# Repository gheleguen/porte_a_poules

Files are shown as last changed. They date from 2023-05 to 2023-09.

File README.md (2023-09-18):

# Porte à poules

Une porte à poules est destiné à automatiser l'ouverture et la fermeture d'un poulailler. Il est équipé d'un capteur de lumière et d'une horloge en temps réel. Le déclenchement de la porte se fait donc à partir d'une certaine heure (défini par l'utilisateur au moyen de potentiomètres) et quand la lumière passe en dessous d'un certain seuil. 

Le système est réalisé sur une base arduino avec un moto-réducteur à courant continu. L'alimentation est opéré par une batterie au plomb chargé par un petit panneau solaire.

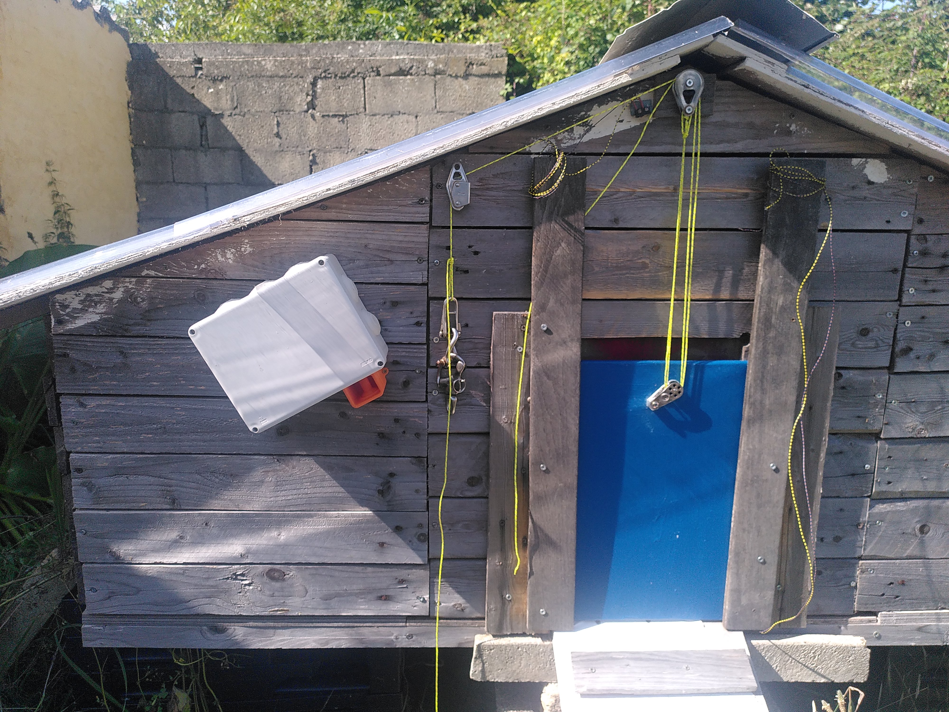
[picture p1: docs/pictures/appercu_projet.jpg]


## Usage de la présente documentation

Toutes la documentation est basé sur une archive git et hébergé sur [github](https://github.com/). 

Afin de fabriquer la porte à poule et de disposer de tous les documents et fichiers nécessaires, je vous recommande de copier l'archive sur votre ordinateur : 
 - En vous rendant directement sur le projet github : https://github.com/gheleguen/porte_a_poules.
 - Ou en exécutant sur un terminal la ligne de commande suivante : ```git clone https://github.com/gheleguen/porte_a_poules```

## 1/ Toutes les clés pour se lancer

### 1.1 Télécharger l'archive

Avant toute chose, [télécharger l'archive du projet](https://github.com/gheleguen/porte_a_poules/archive/refs/heads/main.zip). C'est dans ce dossier que se trouve tous les fichiers de documantations mais aussi les fichiers de découpes ou les modèles d'impression 3D. 

**Ou passer par Git Hub**

Se rendre dans le [git hub](https://github.com/gheleguen/porte_a_poules) et télécharger l'archive complète du projet. 

**Ou en lignes de commandes**

 - Ouvrir un terminal linux,
 - Si ce n'est pas déjà fait installer ```git``` : <pre>sudo apt install git</pre>
 - Se placer dans le dossier de votre ordinateur où vous souhaitez installer enregistrer l'archive.
 - Cloner l'archive : <pre>git clone https://github.com/gheleguen/porte_a_poules</pre> 

### 1.2 L'arborescence de l'archive

 - **docs :** Est le dossier qui contient les documents et images qui constituent la documentation.  Ce sont des fichiers marckdown (.md) que l'on peut ouvrir avec un éditeur de texte.

 - **Hardware :** Le dossier qui contient les fichiers d'impressions 3D, de découpe laser...  

 - **Software :** Le dossier qui contient le code à flasher sur l'arduino.

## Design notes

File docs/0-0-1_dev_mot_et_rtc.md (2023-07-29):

# 0.0.1 -- Un moteur piloté à l'heure

## 1/ Introduction
La première étape du développement de cet outil est de chercher à piloter un moteur à courant continu de 1,5 à 3V au moyen d'une arduino UNO et d'une RTC pour donner l'heure. 
 - Dans cette configuration 2 boutons poussoirs symbolisent, les deux fins de courses. Le moteur devra s'arrêté lorsque le bouton sera enclenché de fin de course correspondant sera enclenché.
 - Une RTC permettra de fournir l'heure en temps réel. Cette donnée permet à la porte de s'ouvrir et de se fermer. 

</br></br>
## 2/ Matériel et fournitures nécessaire
### 2.1 Fournitures
|Dénomination|Visuel|Où se fournir ?|Qt|
|---|---|-----|--|
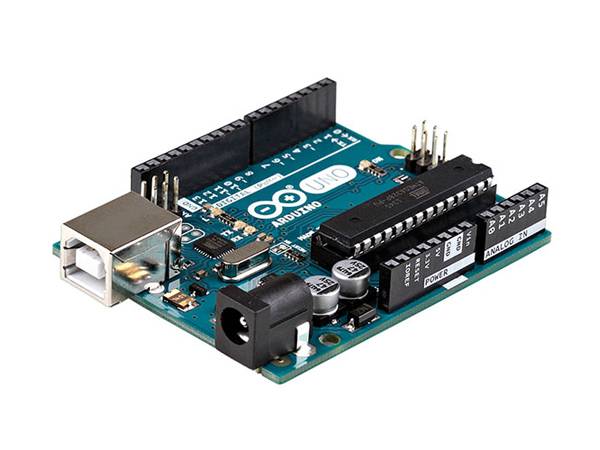
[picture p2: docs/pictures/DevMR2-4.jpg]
|Arduino UNO||Conrad / RS components|1|
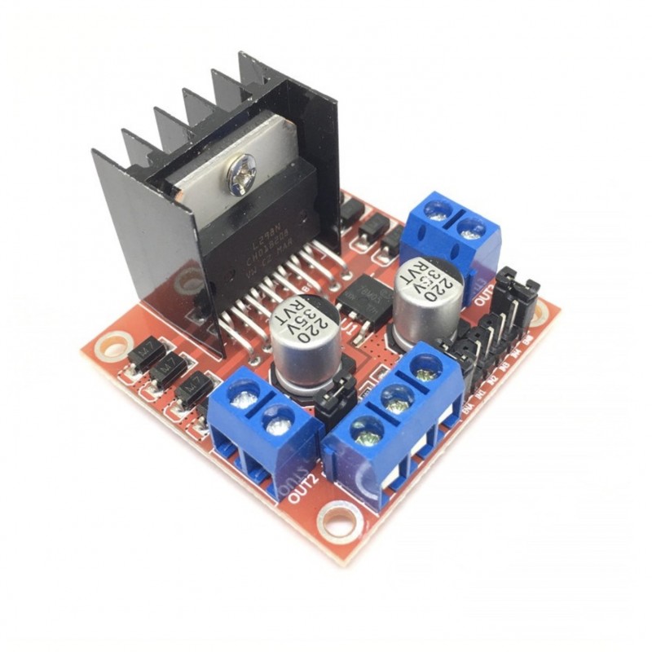
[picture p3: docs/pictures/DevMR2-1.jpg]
DevMR2-1
|Contrôleur moteur - Module L298N||Conrad / RS components|1|
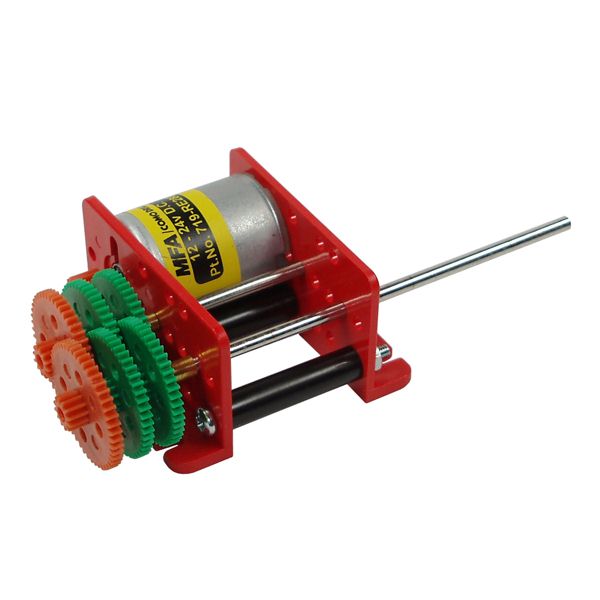
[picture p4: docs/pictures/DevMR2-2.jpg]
DevMR2-2
|Moteur DC (1,5-3v et son reducteur)||RS components|1|
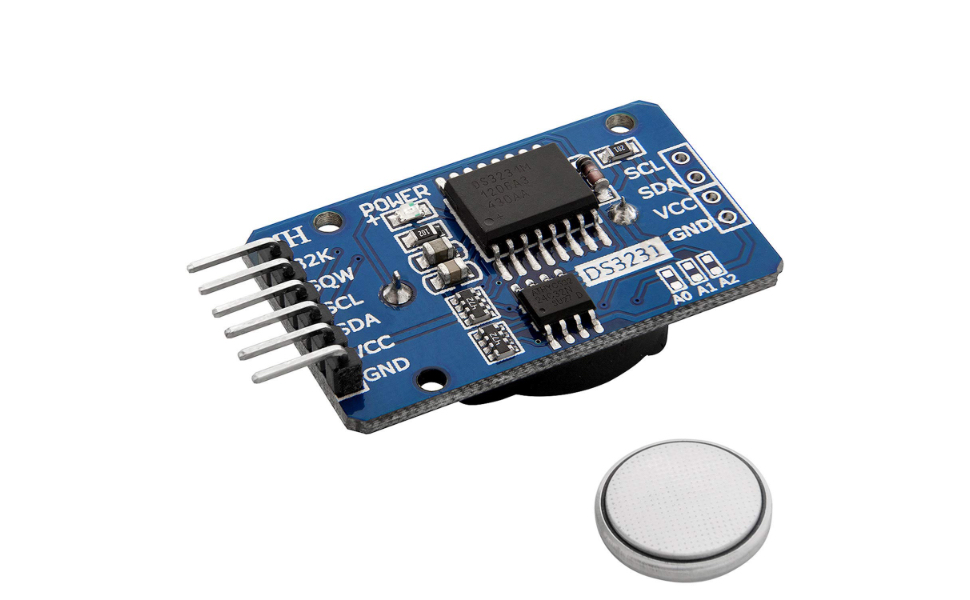
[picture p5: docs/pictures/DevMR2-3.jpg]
|Module horloge RTC DS3231||Conrad / RS components|1|
|Résistances 1Kohm ou autre valeur|||4|
|Boutons poussoirs|||2|
|Batterie 9V ou Bloc piles 9v et pile||Conrad / RS components|1|
|Breadbord|||1|
|Fils de breadbord mâle-mâle et femelle-mâle||||

### 2.2 Matériel
 - Ordinateur
 - [Logiciel Arduino IDE](https://www.arduino.cc/en/software)
 - Câble USB type B vers USB. 

</br></br> 
## 3/ Réalisation
### 3.1 Hardware
Réaliser le circuit représenté ci dessous. [Le fichier fritzing est accessible ici](../hardware)
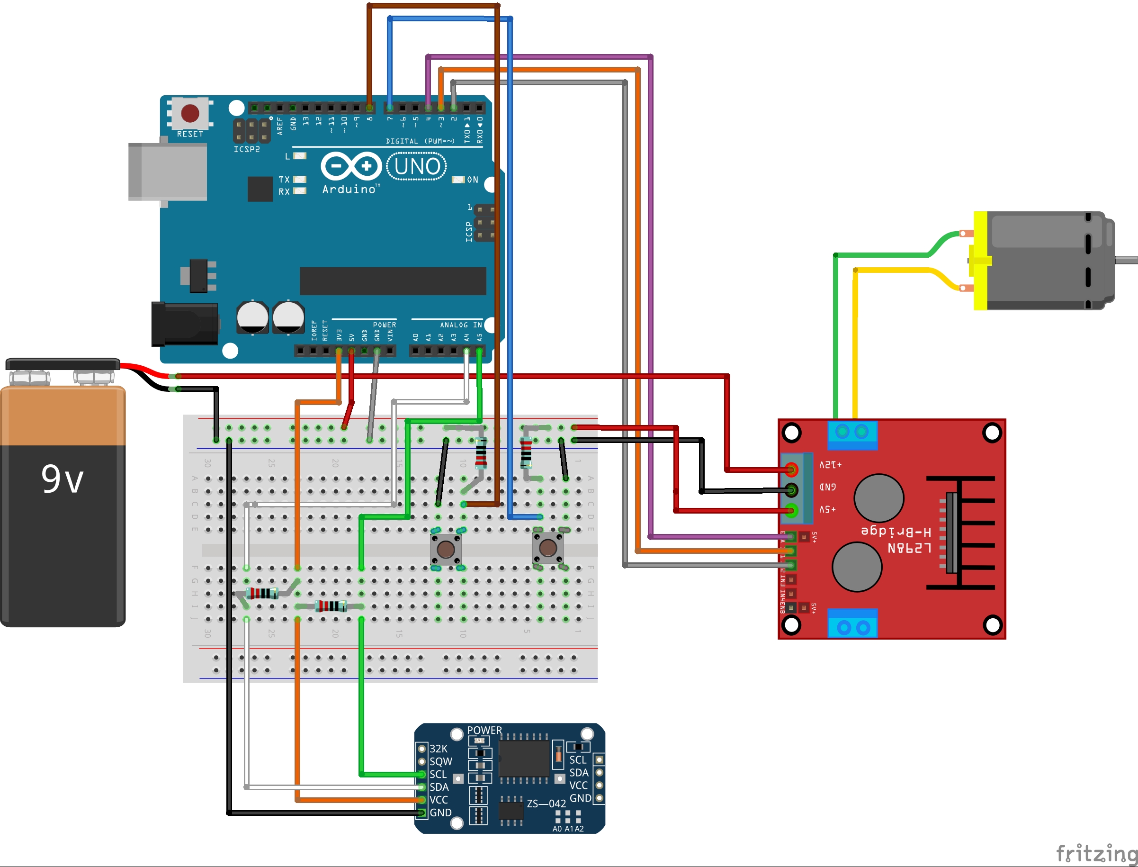
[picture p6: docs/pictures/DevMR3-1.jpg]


### 3.2 Software
Le code suivant se trouvau aussi au format ".ino" dans l'archive dans le dossier "software" sous le nom de "dev_mot_et_rtc.ino".

Flasher au moyen d'Arduino IDE le code suivant :

```cpp
#include <Wire.h>  
#include "DS3231.h"

RTClib RTC;
DS3231 Clock;

//Paramètres de déclenchements de la porte
int Houv = 8; // Heure d'ouverture
int Mouv = 0; // Minute d'ouverture
int Hferm = 17; //Heure de fermeture
int Mferm = 0; // Minute de fermeture

// Branchements
int enA = 4; 
int in1 = 3;
int in2 = 2;
int pin_buttonA = 7; // port numérique lié au bouton poussoir 1
int pin_buttonB = 8; // port numérique lié au bouton poussoir 2

//Introduction de variables
int Year;
int Month;
int Date;
int Hour;
int Minute;
int Second;
int interval = 1;
int Minute_last;
int Date_last;
int i = 0;

void setup()
{
  //Initialise le moniteur série
  Serial.begin(9600);
  Wire.begin(); //for DS3231 for RTC
  
  // Defini tous les ports du contr^leur moteur comme des sorties
  pinMode(enA, OUTPUT);
  pinMode(in1, OUTPUT);
  pinMode(in2, OUTPUT);
  analogWrite(enA, 255); 
  DateTime now = RTC.now();
  Minute = now.minute();
}
 
void loop()
{  
  delay(1000);
  Serial.println();
  Serial.print(Year);
  Serial.print("/");
  Serial.print(Month);
  Serial.print("/");
  Serial.print(Date);
  Serial.print(" ");
  Serial.print(Hour);
  Serial.print(":");
  Serial.print(Minute);
  Serial.print(":");
  Serial.print(Second);
  if (Hour >= Houv && Hour < Hferm && i == 0) { // Si l'heure est supérieur à l'heure minimale d'ouverture et que la porte est fermé
      ouverture(); // Ouverture de la porte
   }
  if (Hour >= Hferm && Hour > Houv && i == 1) { // Si l'heure est supérieur à l'heure minimale de fermeture et que la porte est fermé
      fermeture(); // Ouverture de la porte
   }
  DateTime now = RTC.now();
  Year = now.year();
  Month = now.month();
  Date = now.day();
  Hour = now.hour();
  Minute = now.minute();
  Second = now.second();
}

void ouverture(){
  Serial.println();
  Serial.print("Ouverture de la porte...");
  while (digitalRead(pin_buttonA) == HIGH){ // Tant que le bouton est en position High, le moteur tourne
      //le moteur tourne
      digitalWrite(in1, HIGH);
      digitalWrite(in2, LOW);
  }
  Serial.println();
  Serial.print("Porte ouverte ;-)");
  digitalWrite(in1, LOW);
  digitalWrite(in2, LOW);
  i = 1; // I defini l'etat d'ouverture de la porte, ici i prend la valeur 1 ce qui signifie que la porte est ouverte
  delay(1000);
}

void fermeture(){
  Serial.println();
  Serial.print("Fermeture de la porte...");
  while (digitalRead(pin_buttonB) == HIGH){ // Tant que le bouton est en position High, le moteur tourne
      //le moteur tourne
      digitalWrite(in1, LOW);
      digitalWrite(in2, HIGH);
  }
  Serial.println();
  Serial.print("Porte ferme ;-)");
  digitalWrite(in1, LOW);
  digitalWrite(in2, LOW);
  i = 0;
  delay(1000);
}
```

</br></br>
## 4/ Références et développement. 
J'ai commencé par tester des codes proposé sur le web. Mais tous me rendent des erreurs lié à des librairies.
 - [Ce Tutoriel est réalisé à partir d'un L298N](https://www.instructables.com/Chicken-Coop-Door-Arduino-Based/). Son code ne fonctionne pas du fait d'erreur sur les librairies.
 - [Ce dépot Git Hub peut être intéréssant aussi](https://github.com/chrisuthe/CoopDoor/tree/master/ChickenDoorController) mais comme le précédent il ne fonctionne pas. 

J'ai donc décidé de coder le système moi même :
 - Je suis partis du Tutoriel ci attaché pour faire tourner le moteur[Code et branchements pour faire tourner un moteur avec L298N](https://www.robotique.tech/tutoriel/commander-un-moteur-par-arduino-et-le-module-l298n/). Je suis ainsi parti de ce petit code qui permet de faire tourner le moteur dans un sens puis dans l'autre : 
 ```cpp
// connect motor controller pins to Arduino digital pins
// motor one
int enA = 4;
int in1 = 3;
int in2 = 2;
void setup()
{
  //Initialize Serial Monitor
  Serial.begin(9600);
  // set all the motor control pins to outputs
  pinMode(enA, OUTPUT);
  pinMode(in1, OUTPUT);
  pinMode(in2, OUTPUT);
  analogWrite(enA, 255); 
}
 
void loop()
{  
  //le moteur tourne
  digitalWrite(in1, HIGH);
  digitalWrite(in2, LOW);
  delay(2000);
  //stop le moteur
  digitalWrite(in1, LOW);
  digitalWrite(in2, LOW);
  delay(1000);
  //le moteur tourne dans le sens inverse
  digitalWrite(in1, LOW);
  digitalWrite(in2, HIGH);
  delay(2000);
  //stop le moteur
  digitalWrite(in1, LOW);
  digitalWrite(in2, LOW);
  delay(1000);
} 
 ```

 - J'ai ajouté un bouton poussoir pour le faire tourner jusqu'à ce qu'un bouton soit enfoncé. [J'ai pour cela suivi ce guide de branchement](https://arduino.blaisepascal.fr/le-bouton-poussoir/) et utilisé la ligne de code suivante : 
 
 ```cpp
 if (digitalRead(pin_button) == HIGH) { // si le bouton est pressé ...
      state = !state; // ... inversion de la variable d'état de la LED (allumée<->éteinte)
   }
 ```
  - Sans oublier de déclarer avant le ```void setup() ``` la variable 
  ```cpp
  int pin_button = 2; // port numérique lié au bouton poussoir
  ```
 - Puis j'ai ajouté la RTC, Pour la brancher, j'ai [consulté ce tutoriel](https://arduino-france.site/i2c-scanner/) qui m'a permis de brancher correctement l'I2C sur l'Arduino

|Capteur I2C|Uno|Nano|Mega|
|---|---|---|---|
|GND|GND|GND|GND|
|VCC|3,3v|3,3v|3,3v|
|SDA|A4|A4|20|
|SCL|A5|A5|21|

 - La gestion de l'horloge est obtenu en introduisant les librairies et variables suivantes :

```cpp
#include <Wire.h> // for SD stock
#include "DS3231.h" // for rtc

RTClib RTC;
DS3231 Clock;

int Year;
int Month;
int Date;
int Hour;
int Minute;
int Second;
int interval = 1;
int Minute_last;
int Date_last;
```

 - Puis en définissant l'heure dans le setup : 

```cpp
  DateTime now = RTC.now();
```
 - Et enfin à chaque boucle du loop, on modifie ces variables : 

```cpp
  DateTime now = RTC.now();
  Year = now.year();
  Month = now.month();
  Date = now.day();
  Hour = now.hour();
  Minute = now.minute();
  Second = now.second();
```

 - J'ai mis à l'heure mon horloge en utilisant le code ci dessous. 

```cpp
// Horloge_reglage_heure
// Appel de la bibliothèque
#include <Wire.h>
// Adresse I2C de l'horloge en temps réel
#define ADRESSE_I2C_RTC 0x68
// Indiquez ici l'heure et la date :
byte heure = 00; // 0 à 23
byte minute = 20; // 0 à 59
byte seconde = 0; // 0 à 59
byte numJourSemaine = 3; // dim = 1, sam = 7
byte numJourMois = 2; // 1 à 31
byte mois = 5; // 1 à 12
byte annee = 23; // 0 à 99
void setup(){
Wire.begin();
// Change l'heure et la date de l'horloge en temps réel
Wire.beginTransmission(ADRESSE_I2C_RTC);
Wire.write(0); // Positionner le pointeur de registre sur 00h
Wire.write(decToBcd(seconde));
Wire.write(decToBcd(minute));
Wire.write(decToBcd(heure));
Wire.write(decToBcd(numJourSemaine));
Wire.write(decToBcd(numJourMois));
Wire.write(decToBcd(mois));
Wire.write(decToBcd(annee));
Wire.endTransmission();
}
void loop(){
}
// Convertir les nombres décimaux normaux en décimaux codés binaires
byte decToBcd(byte val){return( (val/10*16) + (val%10));}
```
 - Si ce dernier ne fonctionne pas, c'est probablement que l'adresse I2C n'est pas la bonne. Utiliser un code de détection de port pour y parvenir. Ouvrir le moniteur série. L'adresse retourné par ce programme permettra de remplacer ```0x68``` dans le programme précédent à la ligne ```#define ADRESSE_I2C_RTC 0x68```

```cpp
/*=================================================================
Ce sketch est un scanner I2C: il essaye de communiquer avec toutes 
les adresses I2C possibles et affiche celle(s) qui réponde(nt).
  
                      BRANCHEMENT
* Pin SCD du moule à scanner  ----------->  SCD de l’Arduino
* Pin SDA du moule à scanner  ----------->  SDA de l’Arduino
================================================================ */

#include <Wire.h>
void setup()
{
  Wire.begin();
  Serial.begin(9600);
  Serial.println("\nI2C Scanner");
}

void loop()
{
  byte error, address;
  int nDevices;
  Serial.println("Recherche en cours...");
  nDevices = 0;
  for(address = 1; address < 127; address++ ) 
  {
    Wire.beginTransmission(address);
    error = Wire.endTransmission();

    if (error == 0)
    {
      Serial.print("Equiment I2C trouve a l'addresse 0x");
      if (address<16) 
        Serial.print("0");
      Serial.print(address,HEX);
      Serial.println("  !");
      nDevices++;
    }
    else if (error==4)
    {
      Serial.print("Erreur inconnue a l'address 0x");
      if (address<16) 
        Serial.print("0");
      Serial.println(address,HEX);
    }    
  }
  if (nDevices == 0)
    Serial.println("Aucun Equipement I2C trouve\n");
  else
    Serial.println("Fini\n");

  delay(5000);           
}
```

</br></br>
## 5/ Améliorations
 - Ajouter carte SD pour stocker les données de commandes d'horaire. Ce qui veut dire que les variables devront être lu dans un fichier qui se trouvera dans la SD carte.

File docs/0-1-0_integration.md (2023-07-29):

# 3/Montage élec
**Version 0.1.0**
<br><br>
## 3.1 Introduction
Le système est placé dans une boite étanche de dérivation que l'on trouve en magasin de bricolage. Des modèles 3D sont disponible dans l'archives pour imprimer en 3D les différentes pièces additionnels.

La partie ici présnete traite de l'intégration de l'électronique dans la boite de dérivation. Le résultat attendu est ceci : 
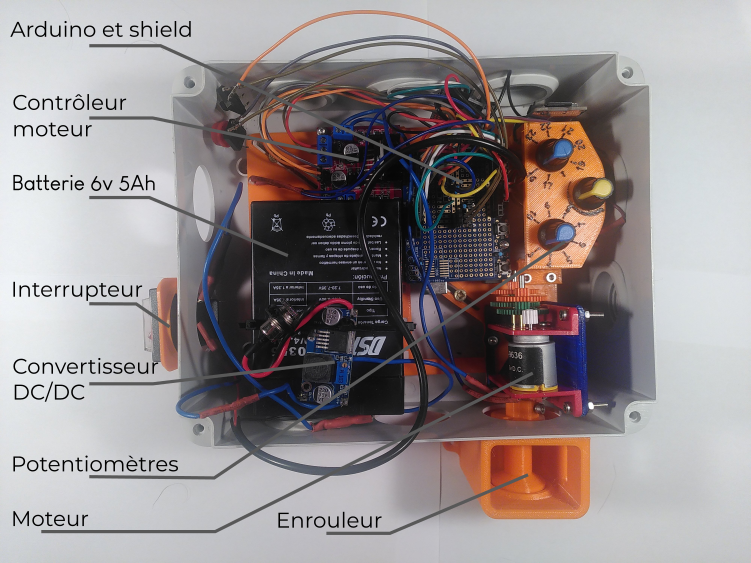
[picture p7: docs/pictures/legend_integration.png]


<br><br>
## 3.2 Réalisation

 - Au moyen de 4 vis M3 et de 4 écrous fixer la carte arduino sur la plaque de fixation. 
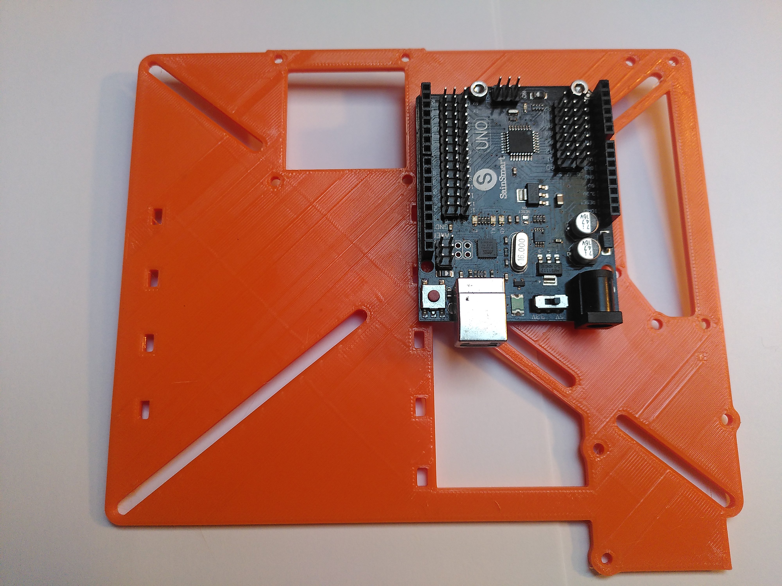
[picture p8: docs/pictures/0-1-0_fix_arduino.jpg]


- Insérer les 3 potentiomètres dans les supports en forçant. On prendra soin de placer le potentiomètre qui sert au réglage du seuil de luminosité sur la pointe. 
 - Visser le support de potentiomètres sur la gauche de la carte arduino.
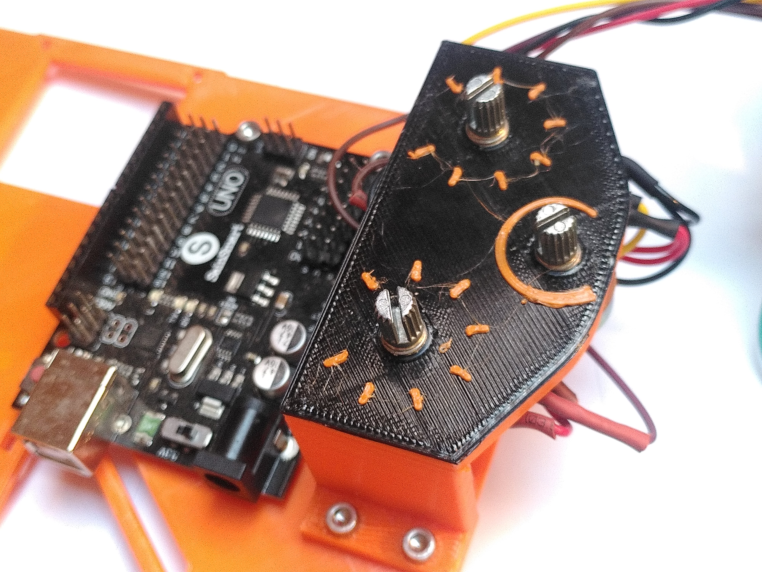
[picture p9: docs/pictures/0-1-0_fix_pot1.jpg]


 - Insérer sur les potentiomètres la plaque avec les graduations. Sérer avec les écrous fournis avec les potentiomètres. 
 - Insérer les boutons.
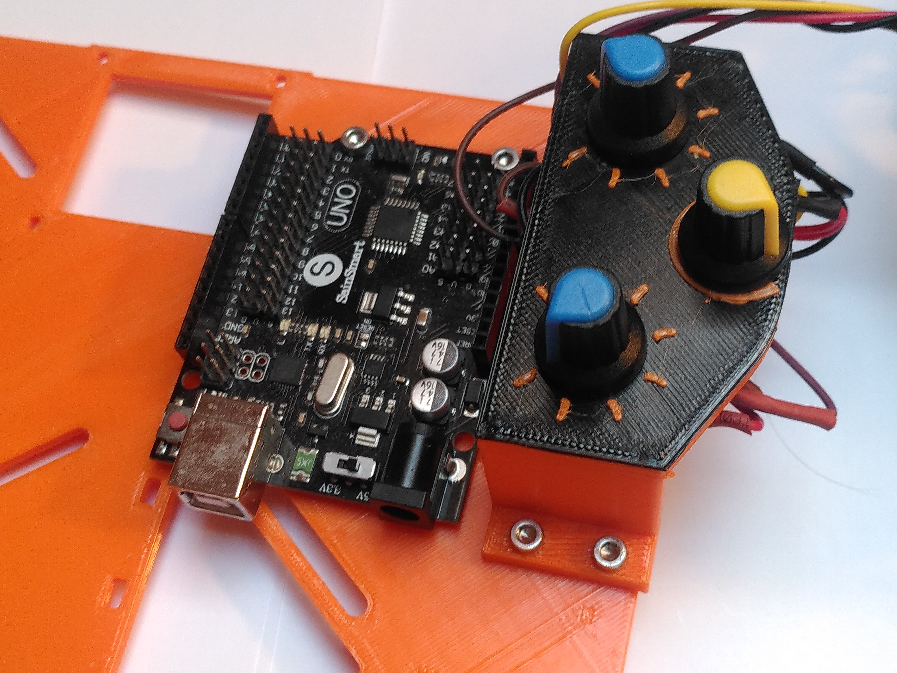
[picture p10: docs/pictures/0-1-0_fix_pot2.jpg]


 - Fixer le contrôleur du moteur à droite de la carte arduino. 
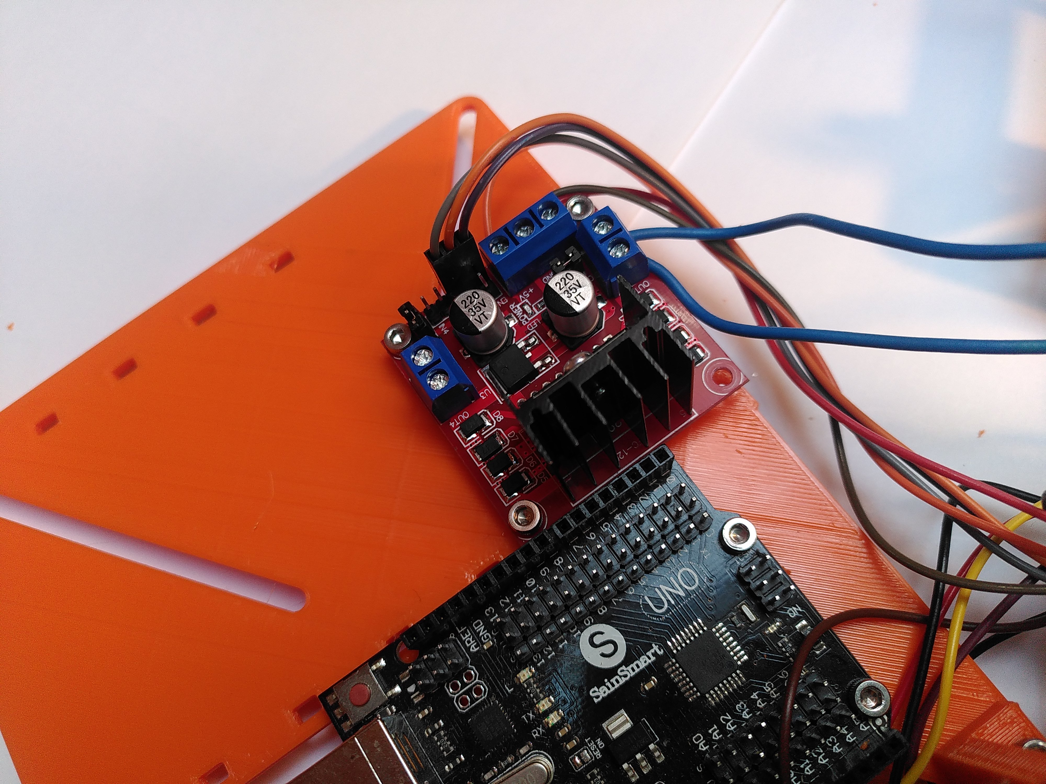
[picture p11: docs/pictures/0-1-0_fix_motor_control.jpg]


 - Visser le réducteur du moteur sur le support au moyen de 3 vis M3 et de 3 écrous.
 - Visser le support de moteur en dessous du porte potentiomètres. 
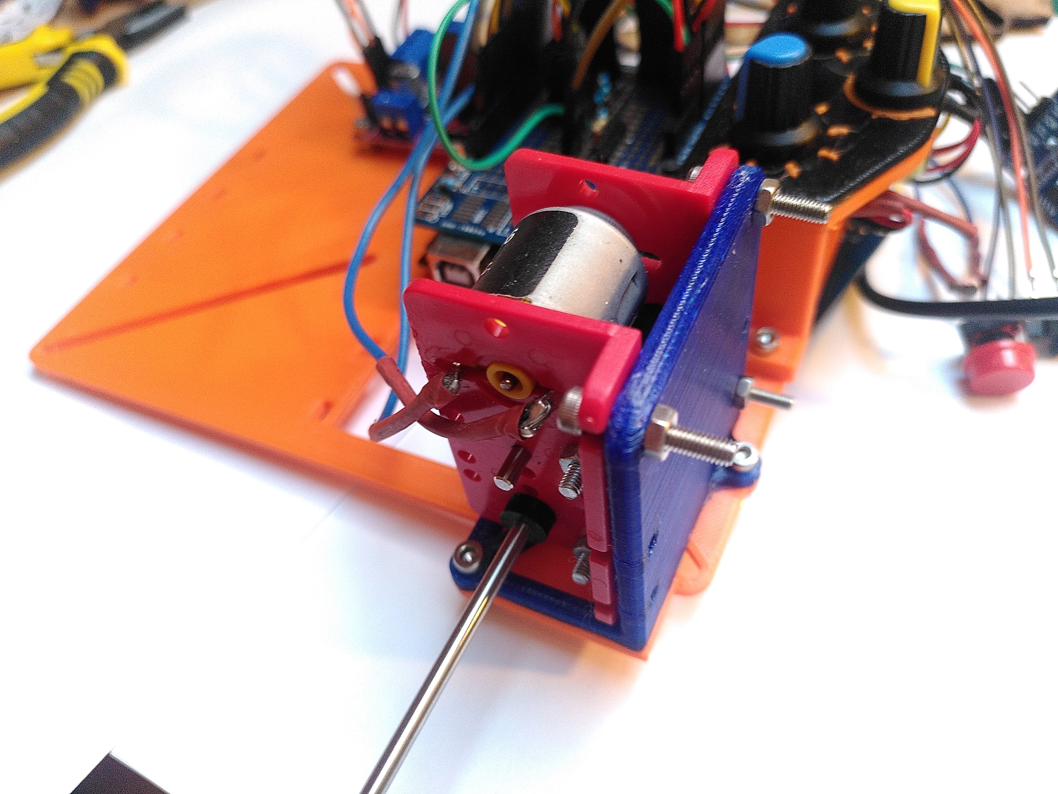
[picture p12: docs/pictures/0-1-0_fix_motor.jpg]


 - Installer le shild et ses câbles sur le dessus de l'Arduino en veillant à ce que les broches tombent au bon endroit. 
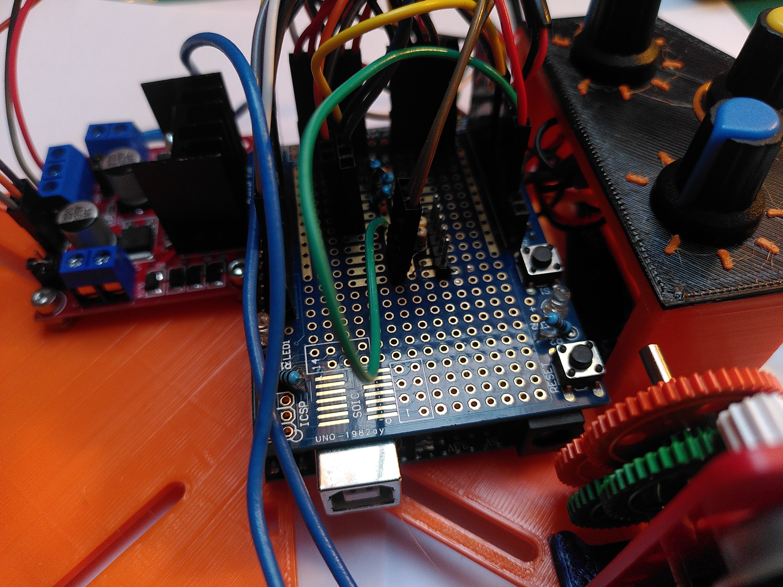
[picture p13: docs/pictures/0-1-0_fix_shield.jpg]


 - Au moyen de coliers de serrages, fixer la batterie en positionnant les connectiques vers le bas afin de limiter tout contact avec le contrôleur moteur. 
 - Les modules RTC et portes cartes SD seront maintenu au moyens de colliers de serrages. 
 - Réaliser un câblage pour alimenter le circuit et le couper au moyen de l'interrupteur.

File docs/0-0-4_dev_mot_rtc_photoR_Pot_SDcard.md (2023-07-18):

# 0.0.4 -- Elec -- Une carte SD qui stocke un LOG pour le débogage 
## 1/ Introduction
Quatrième étape, ajouter un moyen de contrôler le travail de la porte à poules. Ici, je propose l'ajout d'un lecteur de carte SD. Le système écrira dans un fichier "log.csv" les informations d'heure et de date d'ouverture et de fermeture de la porte. Ainsi que 3 paramètres suplémentaires (Heure d'ouverture, Heure de fermeture et l'intensité lumineuse au moment de la fermeture.)^

</br></br>
## 2/ Matériel et fournitures nécessaire
### 2.1 Fournitures
|Dénomination|Visuel|Où se fournir ?|Qt|
|---|---|-----|--|
|Arduino UNO||Conrad / RS components|1|
|Contrôleur moteur - Module L298N|DevMR2-1|Conrad / RS components|1|
|Moteur DC (1,5-3v et son reducteur)|DevMR2-2|RS components|1|
|Module horloge RTC DS3231||Conrad / RS components|1|
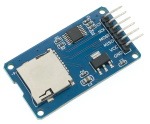
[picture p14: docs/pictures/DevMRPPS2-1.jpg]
|Module porte carte SD et SDHC *notes : ce modèle contient un convertisseur de tension permettant de l'alimenter en 5V comme en 3,3v*||Conrad / RS components|1|
|Carte Micro SD||Conrad / RS components|1|
|Résistances 1Kohm ou autre valeur|||4|
|Résistances 10Kohm|||1|
|Boutons poussoirs|||2|
|Photo-résistance|||1|
|Batterie 5-6V ou Bloc piles 4* AA et piles||Conrad / RS components|1|
|Potentiomètres||Conrad / RS components|3|
|Breadbord|||1|
|Fils de breadbord mâle-mâle et femelle-mâle||||

### 2.2 Matériel
 - Ordinateur
 - [Logiciel Arduino IDE](https://www.arduino.cc/en/software)
 - Câble USB type B vers USB. 

</br></br> 
## 3/ Réalisation
### 3.1 Hardware
Réaliser le circuit représenté ci dessous. Le fichier fritzing est disponible dans le dossier "hardware" du dépôt.

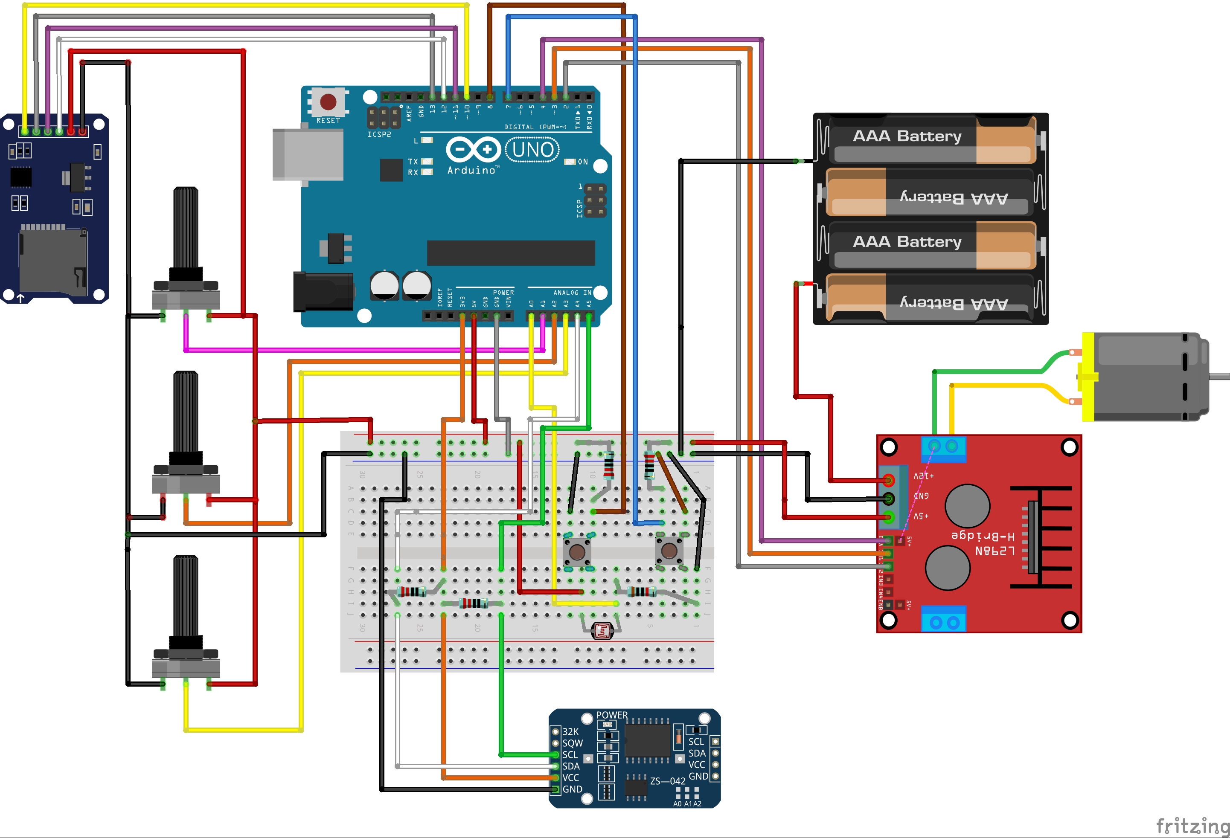
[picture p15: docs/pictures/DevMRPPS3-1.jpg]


### 3.2 Software
Le code suivant se trouve aussi au format ".ino" dans l'archive dans le dossier "software" sous le nom de "dev_mot_et_rtc.ino".

Flasher au moyen d'Arduino IDE le code suivant :

```cpp
//Librairies
#include <Wire.h>  
#include "DS3231.h"
#include <SPI.h>
#include <SD.h>

RTClib RTC;
DS3231 Clock;

// Branchements des composants
int enA = 4; //EnA du controleur moteur
int in1 = 3; //in1 du controleur moteur
int in2 = 2; //in2 du controleur moteur
int pin_buttonA = 7; // port numérique lié au bouton poussoir 1
int pin_buttonB = 8; // port numérique lié au bouton poussoir 2
int photoR = A0; // Port Analogique de la photo-résistance
int PotHouv = A1; //Port analogique du potentiomètre 1
int PotHferm = A2; // Port analogique du potentiomètre 2
int PotLum = A3; // Port analogique du potentiomètre 3
const int pinBranchementCS = 10; // Le « 10 » indiquant ici que la broche CS (SS) du lecteur de carte SD

//Paramètres de déclenchements de la porte
int Mouv = 0; // Minute d'ouverture
int Mferm = 0; // Minute de fermeture
int vPotHouv = 0;      // Variable où on stock la valeur du potentiomètre
int vPotHferm = 0;      // Variable où on stock la valeur du potentiomètre
int vPotLum = 0;      // Variable où on stock la valeur du potentiomètre
float Houv = 8;  // Variable où on stock l'heure d'ouverture
float Hferm = 20;  // Variable où on stock l'heure de fermeture
float LumD = 20;  // Variable où on stock le seuil de lumière qui sera utilisé
const char* nomDuFichier = "log.csv"; // Nom du log sur carte SD
File monFichier;

//Introduction de variables
int Year;
int Month;
int Date;
int Hour;
int Minute;
int Second;
int interval = 1;
int Minute_last;
int Date_last;
int i;  //i permettra à l'arduino de savoir si il fait jour ou nuit
int PR; // Varible qui stockera la valeur de la photorésistance

void setup()
{
  Serial.begin(9600); //Initialise le moniteur série
  Wire.begin(); //Initialisation du bus I2C
  SD.begin(pinBranchementCS); // démarre le lecteur de carte SD
  
  // Defini tous les ports du controleur moteur comme des sorties
  pinMode(enA, OUTPUT);
  pinMode(in1, OUTPUT);
  pinMode(in2, OUTPUT);
  analogWrite(enA, 255); 
  DateTime now = RTC.now();
  Minute = now.minute();
  
  // cette fonction va permettre de determiner si il fait jour ou si il fait nuit et de définir i en conséquence. 
  if (Hour >= Houv && Hour <Hferm) {
    i = 1 ; // I prend 1 ce qui veut dire qu'il fait jour
  }
  else {
    i = 0 ; // I prend 0 ce qui veut dire qu'il fait nuit
  }
}
void loop()
{  
  delay(1000);
  PR = analogRead(photoR); // On lit la valeur de la photo-resistance
  vPotHouv = analogRead(PotHouv); // on lit la valeur du potentiometre 1 
  vPotHferm = analogRead(PotHferm); // on lit la valeur du potentiometre 2
  vPotLum = analogRead(PotLum); // on lit la valeur du potentiometre 3
  Houv = ((vPotHouv*7.00/1023.00)+3); // Calcul de l'heure d'ouverture
  Hferm = ((vPotHferm*7.00/1023.00)+16); // Calcul de l'heure de fermeture
  LumD = ((vPotLum*400.00/1023.00)+623); // Calcul du seuil de luminosité 
  affichage();
  
  if (Hour >= Houv && Hour < Hferm && i == 0 && PR > LumD) { // Si l'heure est supérieur à l'heure minimale d'ouverture et que la porte est fermé
      ouverture(); // Ouverture de la porte
   }
  if (Hour >= Hferm && Hour > Houv && i == 1 && PR < LumD) { // Si l'heure est supérieur à l'heure minimale de fermeture et que la porte est fermé
      fermeture(); // Ouverture de la porte
   }
  DateTime now = RTC.now();
  Year = now.year();
  Month = now.month();
  Date = now.day();
  Hour = now.hour();
  Minute = now.minute();
  Second = now.second();
}

// Fonction permettant l'ouverture de la porte
void ouverture(){
  monFichier = SD.open(nomDuFichier, FILE_WRITE);
  if (monFichier) {
    monFichier.print("ouverture");
    monFichier.print(";");
    monFichier.print(Year);
    monFichier.print("-");
    monFichier.print(Month);
    monFichier.print("-");
    monFichier.print(Date);
    monFichier.print(";");
    monFichier.print(Hour);
    monFichier.print(":");
    monFichier.print(Minute);
    monFichier.print(";");
    monFichier.print(Houv);
    monFichier.print(";");
    monFichier.print(Hferm);
    monFichier.print(";");
    monFichier.println(PR);
    monFichier.close(); // Fermeture du fichier
    Serial.println("Ecriture terminee.");
  }
  else {
    Serial.println(F("Echec d'ouverture en ecriture, sur la carte SD !"));
  }
  Serial.println();
  Serial.print("Ouverture de la porte...");
  while (digitalRead(pin_buttonA) == HIGH){ // Tant que le bouton est en position High, le moteur tourne
      //le moteur tourne
      digitalWrite(in1, HIGH);
      digitalWrite(in2, LOW);
  }
  Serial.println();
  Serial.print("Porte ouverte ;-)");
  digitalWrite(in1, LOW);
  digitalWrite(in2, LOW);
  i = 1; // I defini l'etat d'ouverture de la porte, ici i prend la valeur 1 ce qui signifie que la porte est ouverte
  delay(1000);
}

// Fonction permettant la fermeture de la porte
void fermeture(){
    monFichier = SD.open(nomDuFichier, FILE_WRITE);
  if (monFichier) {
    monFichier.print("fermeture");
    monFichier.print(";");
    monFichier.print(Year);
    monFichier.print("-");
    monFichier.print(Month);
    monFichier.print("-");
    monFichier.print(Date);
    monFichier.print(";");
    monFichier.print(Hour);
    monFichier.print(":");
    monFichier.print(Minute);
    monFichier.print(";");
    monFichier.print(Houv);
    monFichier.print(";");
    monFichier.print(Hferm);
    monFichier.print(";");
    monFichier.println(PR);
    monFichier.close(); // Fermeture du fichier
    Serial.println("Ecriture terminee.");
  }
  else {
    Serial.println(F("Echec d'ouverture en ecriture, sur la carte SD !"));
  }
  Serial.println();
  Serial.print("Fermeture de la porte...");
  while (digitalRead(pin_buttonB) == HIGH){ // Tant que le bouton est en position High, le moteur tourne
      //le moteur tourne
      digitalWrite(in1, LOW);
      digitalWrite(in2, HIGH);
  }
  Serial.println();
  Serial.print("Porte ferme ;-)");
  digitalWrite(in1, LOW);
  digitalWrite(in2, LOW);
  i = 0;
  delay(1000);
}

// Fonction permettant l'affichage des données sur le moniteur serie
void affichage() {
  Serial.println();
  Serial.print("Date: ");
  Serial.print(Year);
  Serial.print("/");
  Serial.print(Month);
  Serial.print("/");
  Serial.print(Date);
  Serial.print(" ");
  Serial.print(Hour);
  Serial.print(":");
  Serial.print(Minute);
  Serial.print(":");
  Serial.print(Second);
  Serial.println();
  Serial.print("Parametres: ");
  Serial.print(Houv);
  Serial.print("  ");
  Serial.print(Hferm);
  Serial.print("  ");
  Serial.print(LumD);
  Serial.println();
  Serial.print("Valeur actuel de la Photo-resistance : ");
  Serial.println(PR);
  Serial.print("Valeur de i : ");
  Serial.println(i);
}
```

</br></br>
## 4/ Références et développement. 
Toutes le informations à propos du branchement et de l'usage du module porte carte SD viennent d'un [excellent tutoriel de Passion electronique](https://passionelectronique.fr/carte-sd-arduino/)

**Branchements :** 

|Module lecteur SD|Uno|Nano|Mega|
|---|---|---|---|
|**Broche CS**|D10|D10|53|
|**Broche SCK**|D13|D13|52|
|**Broche MOSI**|D11|D11|51|
|**Broche MISO**|D12|D12|50|
|**Broche VCC**|5v|5v|5v|
|**Broche GND**|GND|GND|GND|

La librairie utilisé est "SD.h" une librairies installé par défaut avec Arduino IDE. Donc aucune installation de librairie n'est nécessaire.

La présente documentation ne traite que l'écriture sur la carte SD, pour la lecture, consulter le tutoriel dont le lien figure plus haut. 

On commence par déclarer les librairies utilisés : 
```cpp
#include <SPI.h>
#include <SD.h>
```

Puis il faudra initialiser la classe "SD". Egalement il ser nécéssaire de préciser le branchement de la PIN CS (ou SS), ici sur D10. 
```cpp
const int pinBranchementCS = 10; // Le « 10 » indiquant ici que la broche CS (SS) de votre lecteur de carte SD est branché sur la pin D10 de votre Arduino
SD.begin(pinBranchementCS); // Cette fonction retournere "True" si l'initialisation est ok. Elle pourra être utilisé pour générer un message d'erreur. 
```

Pour finir dans init, il faudra déclarer la variable "nomDuFichier" :
```cpp
const char* nomDuFichier = "log.csv"; // Nom du log sur carte SD
```

De plus, il faudra dans le ```void loop``` éxecuter une fonction "open". Cette fonction renverra une erreur si l'on essaye d'ouvrir un fichier en lecture qui n'existe pas. Mais en écriture dans le cas où le fichier n'existe pas il le créera. 
```cpp
SD.open(nomDuFichier, FILE_WRITE); // Ouvr en écriture
SD.open(nomDuFichier, FILE_READ); // Ouvre en lecture
```

Attention, lorsqu'un fichier n'est plus utilisé, il faut le refermer. On utilise pour cela la fonction "close".
```cpp
SD.close();
```

Voilà ce que donne une section d'écriture de texte dans le fichier en question : 

```cpp
    monFichier.print("ouverture");
    monFichier.print(";");
    monFichier.print(Year);
    monFichier.print("-");
    monFichier.print(Month);
    monFichier.print("-");
    monFichier.print(Date);
    monFichier.print(";");
    monFichier.print(Hour);
    monFichier.print(":");
    monFichier.print(Minute);
    monFichier.print(";");
    monFichier.print(Houv);
    monFichier.print(";");
    monFichier.print(Hferm);
    monFichier.print(";");
    monFichier.println(PR);
    monFichier.close();   
```
Ici j'écris une ligne dans un csv séparé par des ";" pour pouvoir par la suite analyser ces données et faire des statistiques. 

</br></br>
## 5/ Améliorations
 - Ajouter un écran LCD pour donner l'heure des dernières ouvertures, fermetures et valeur de lumière. 
 - Si la lecture de l'intensité lumineuse pose un problème, peut-être étudier des techniques de lissage de courbe tel qu'utiliser une moyenne glissante, [comme documenté ici](https://www.aranacorp.com/fr/implementation-de-la-moyenne-glissante-dans-arduino/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,l'%C3%A9tablissement%20de%20la%20moyenne.).

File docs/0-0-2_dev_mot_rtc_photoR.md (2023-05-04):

# 0.0.2 -- Ajout d'un capteur de lumière 
## 1/ Introduction
Seconde étape, insérer à notre système une lecture de l'intensité lumineuse ambiante. 
 - Ajouter une photo résistance
 - Il devra y avoir des heures de sécurité pour que même si la lumière augmente en peine nuit (lampe torche), la porte reste fermé.

</br></br>
## 2/ Matériel et fournitures nécessaire
### 2.1 Fournitures
|Dénomination|Visuel|Où se fournir ?|Qt|
|---|---|-----|--|
|Arduino UNO||Conrad / RS components|1|
|Contrôleur moteur - Module L298N|DevMR2-1|Conrad / RS components|1|
|Moteur DC (1,5-3v et son reducteur)|DevMR2-2|RS components|1|
|Module horloge RTC DS3231||Conrad / RS components|1|
|Résistances 1Kohm ou autre valeur|||4|
|Résistances 10Kohm|||1|
|Boutons poussoirs|||2|
|Photo-résistance|||1|
|Batterie 9V ou Bloc piles 9v et pile||Conrad / RS components|1|
|Breadbord|||1|
|Fils de breadbord mâle-mâle et femelle-mâle||||

### 2.2 Matériel
 - Ordinateur
 - [Logiciel Arduino IDE](https://www.arduino.cc/en/software)
 - Câble USB type B vers USB. 

</br></br>
## 3/ Réalisation
### 3.1 Hardware
Réaliser le circuit représenté ci dessous. Le fichier fritzing est disponible dans le dossier "hardware" du dépôt.
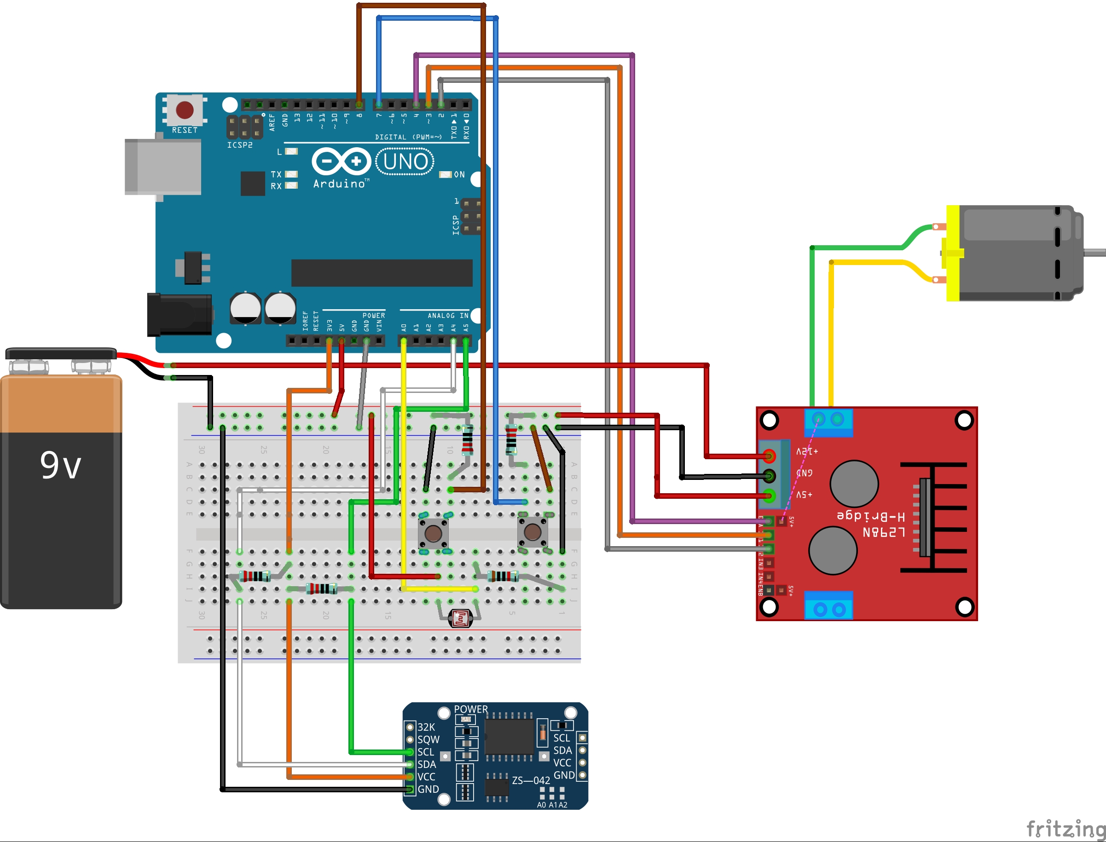
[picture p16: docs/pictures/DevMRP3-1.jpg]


### 3.2 Software
Le code suivant se trouv aussi au format ".ino" dans l'archive dans le dossier "software" sous le nom de "dev_mot_et_rtc.ino".

Flasher au moyen d'Arduino IDE le code suivant :

```cpp
#include <Wire.h>  
#include "DS3231.h"

RTClib RTC;
DS3231 Clock;

//Paramètres de déclenchements de la porte
int Houv = 8; // Heure d'ouverture
int Mouv = 0; // Minute d'ouverture
int Hferm = 17; //Heure de fermeture
int Mferm = 0; // Minute de fermeture

// Branchements
int enA = 4; 
int in1 = 3;
int in2 = 2;
int pin_buttonA = 7; // port numérique lié au bouton poussoir 1
int pin_buttonB = 8; // port numérique lié au bouton poussoir 2
int photoR = A0; // Port Analogique de la photo-résistance

//Introduction de variables
int Year;
int Month;
int Date;
int Hour;
int Minute;
int Second;
int interval = 1;
int Minute_last;
int Date_last;
int i = 1; //i prend la valeur 1 soit la porte est ouverte (souvent l'installation se fera plutôt en journée)
int PR; // Varible qui stockera la valeur de la photorésistance

void setup()
{
  //Initialise le moniteur série
  Serial.begin(9600);
  Wire.begin(); //for DS3231 for RTC
  
  // Defini tous les ports du contr^leur moteur comme des sorties
  pinMode(enA, OUTPUT);
  pinMode(in1, OUTPUT);
  pinMode(in2, OUTPUT);
  analogWrite(enA, 255); 
  DateTime now = RTC.now();
  Minute = now.minute();
}
 
void loop()
{  
  delay(1000);
  PR = analogRead(photoR);
  Serial.println();
  Serial.print(Year);
  Serial.print("/");
  Serial.print(Month);
  Serial.print("/");
  Serial.print(Date);
  Serial.print(" ");
  Serial.print(Hour);
  Serial.print(":");
  Serial.print(Minute);
  Serial.print(":");
  Serial.print(Second);
  Serial.println();
  Serial.println(PR);
  if (Hour >= Houv && Hour < Hferm && i == 0 && PR > 900) { // Si l'heure est supérieur à l'heure minimale d'ouverture et que la porte est fermé
      ouverture(); // Ouverture de la porte
   }
  if (Hour >= Hferm && Hour > Houv && i == 1 && PR < 850) { // Si l'heure est supérieur à l'heure minimale de fermeture et que la porte est fermé
      fermeture(); // Ouverture de la porte
   }
  DateTime now = RTC.now();
  Year = now.year();
  Month = now.month();
  Date = now.day();
  Hour = now.hour();
  Minute = now.minute();
  Second = now.second();
}

void ouverture(){
  Serial.println();
  Serial.print("Ouverture de la porte...");
  while (digitalRead(pin_buttonA) == HIGH){ // Tant que le bouton est en position High, le moteur tourne
      //le moteur tourne
      digitalWrite(in1, HIGH);
      digitalWrite(in2, LOW);
  }
  Serial.println();
  Serial.print("Porte ouverte ;-)");
  digitalWrite(in1, LOW);
  digitalWrite(in2, LOW);
  i = 1; // I defini l'etat d'ouverture de la porte, ici i prend la valeur 1 ce qui signifie que la porte est ouverte
  delay(1000);
}

void fermeture(){
  Serial.println();
  Serial.print("Fermeture de la porte...");
  while (digitalRead(pin_buttonB) == HIGH){ // Tant que le bouton est en position High, le moteur tourne
      //le moteur tourne
      digitalWrite(in1, LOW);
      digitalWrite(in2, HIGH);
  }
  Serial.println();
  Serial.print("Porte ferme ;-)");
  digitalWrite(in1, LOW);
  digitalWrite(in2, LOW);
  i = 0;
  delay(1000);
}
```

</br></br>
## 4/ Références et développement. 
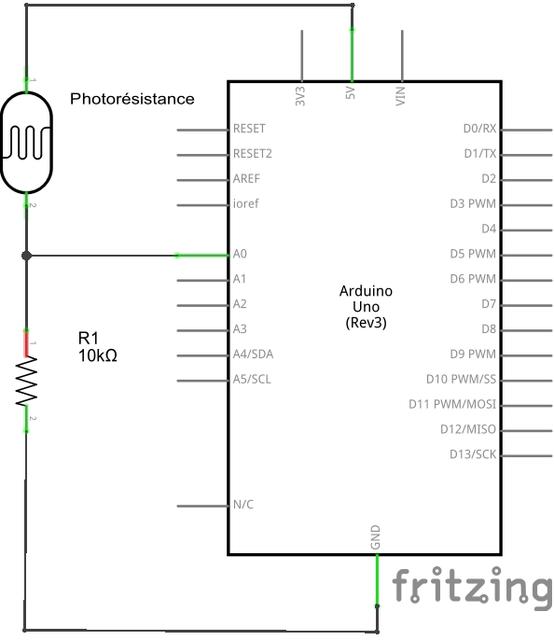
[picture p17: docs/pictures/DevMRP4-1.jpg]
DevMRP4-1
Je me suis servi de [ce tutoriel](https://www.carnetdumaker.net/articles/mesurer-la-luminosite-ambiante-avec-une-photoresistance-et-une-carte-arduino-genuino/). Le branchement est celui d'un diviseur de tension (2 résistances). </br></br>
*crédit : © TamiaLab 2016*

Pour brancher la photorésistance et la tester au moyen du code suivant : 
```cpp
/*
 * Code d'exemple pour une photorésistance.
 */

// Fonction setup(), appelée au démarrage de la carte Arduino
void setup() {

  // Initialise la communication avec le PC
  Serial.begin(9600);
}

// Fonction loop(), appelée continuellement en boucle tant que la carte Arduino est alimentée
void loop() {
  
  // Mesure la tension sur la broche A0
  int valeur = analogRead(A0);
  
  // Envoi la mesure au PC pour affichage et attends 250ms
  Serial.println(valeur);
  delay(250);
}
```

</br></br>
## 5/ Améliorations
 - Ajouter un module de carte SD qui contiendra les valeurs des variables. Pour ne pas avoir à flasher la carte pour chaque besoin. 
 - Ajouter un écran LCD pour donner l'heure des dernières ouvertures, fermetures et valeur de lumière. 
 - Pour le contrôle utilisateur, utiliser 3 potentiomètre que l'on pourra graduer. 2 pour les bornes d'heures et 1 pour la limite de déclenchement (graduer avec un petit soleil et une lune). 
 - Si la lecture de l'intensité lumineuse pose un problème, peut-être étudier des techniques de lissage de courbe tel qu'utiliser une moyenne glissante, [comme documenté ici](https://www.aranacorp.com/fr/implementation-de-la-moyenne-glissante-dans-arduino/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,l'%C3%A9tablissement%20de%20la%20moyenne.).

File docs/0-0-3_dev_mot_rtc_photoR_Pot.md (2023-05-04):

# 0.0.3 -- Trois potentiomètres pour permettre à l'utilisateur de faire les réglages
Troisième étape, insérer à notre système un moyen pour l'utilisateur de régler les paramètres. 
 - 3 potentiomètres (2 pour l'heure d'ouverture et de fermeture / 1 pour le seuil de lumière)

</br></br>
## 2/ Matériel et fournitures nécessaire
### 2.1 Fournitures
|Dénomination|Visuel|Où se fournir ?|Qt|
|---|---|-----|--|
|Arduino UNO||Conrad / RS components|1|
|Contrôleur moteur - Module L298N|DevMR2-1|Conrad / RS components|1|
|Moteur DC (1,5-3v et son reducteur)|DevMR2-2|RS components|1|
|Module horloge RTC DS3231||Conrad / RS components|1|
|Résistances 1Kohm ou autre valeur|||4|
|Résistances 10Kohm|||1|
|Boutons poussoirs|||2|
|Photo-résistance|||1|
|Batterie 9V ou Bloc piles 9v et pile||Conrad / RS components|1|
|Potentiomètres||Conrad / RS components|3|
|Breadbord|||1|
|Fils de breadbord mâle-mâle et femelle-mâle||||

### 2.2 Matériel
 - Ordinateur
 - [Logiciel Arduino IDE](https://www.arduino.cc/en/software)
 - Câble USB type B vers USB. 
 
</br></br>
## 3/ Réalisation
### 3.1 Hardware
Réaliser le circuit représenté ci dessous. Le fichier fritzing est disponible dans le dossier "hardware" du dépôt.
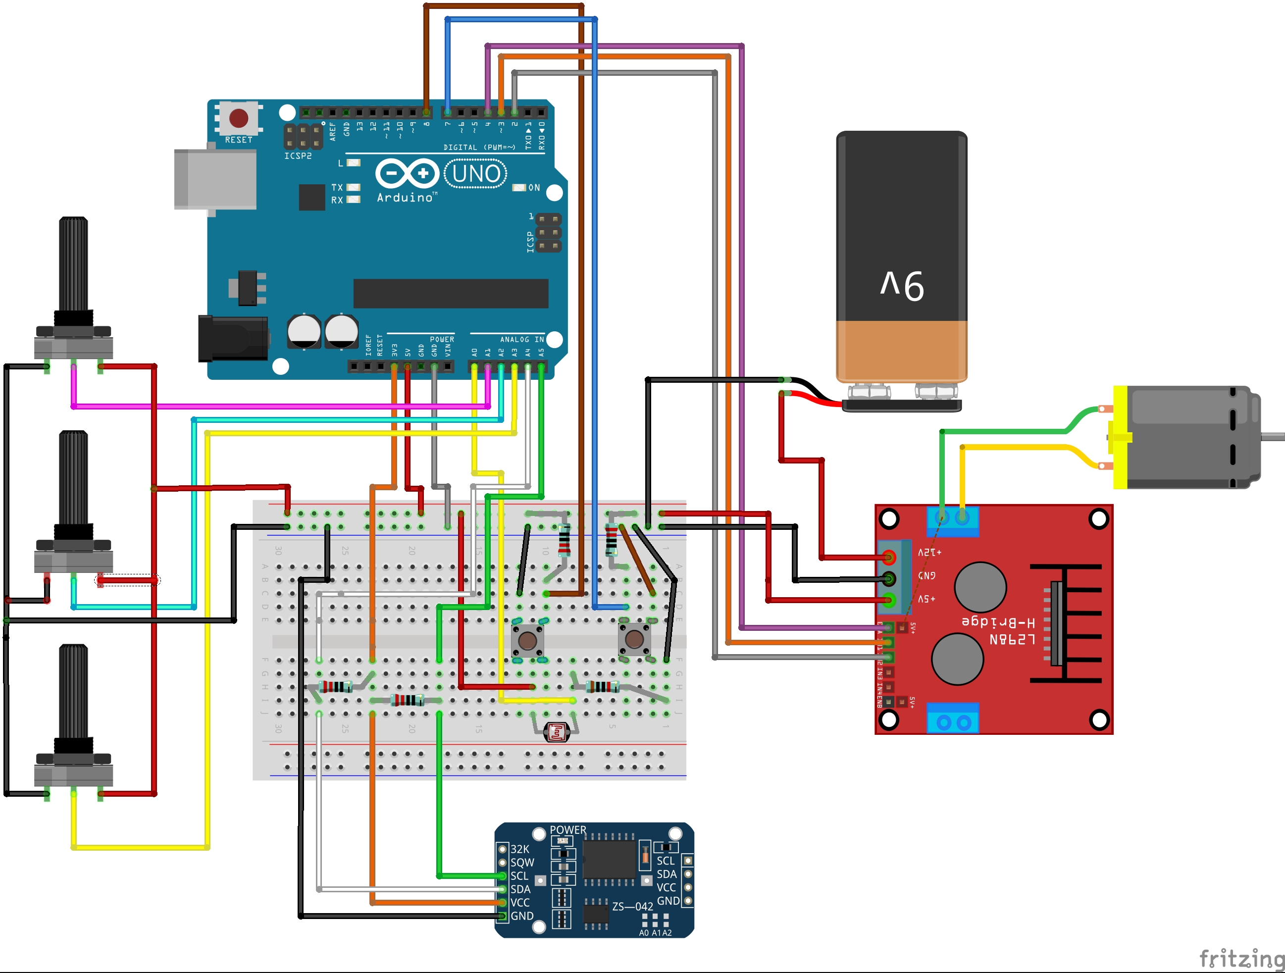
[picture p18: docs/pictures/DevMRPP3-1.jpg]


### 3.2 Software
Le code suivant se trouv aussi au format ".ino" dans l'archive dans le dossier "software" sous le nom de "dev_mot_et_rtc.ino".

Flasher au moyen d'Arduino IDE le code suivant :

```cpp
//Librairies
#include <Wire.h>  
#include "DS3231.h"

//Librairies
#include <Wire.h>  
#include "DS3231.h"

RTClib RTC;
DS3231 Clock;

// Branchements des composants
int enA = 4; //EnA du controleur moteur
int in1 = 3; //in1 du controleur moteur
int in2 = 2; //in2 du controleur moteur
int pin_buttonA = 7; // port numérique lié au bouton poussoir 1
int pin_buttonB = 8; // port numérique lié au bouton poussoir 2
int photoR = A0; // Port Analogique de la photo-résistance
int PotHouv = A1; //Port analogique du potentiomètre 1
int PotHferm = A2; // Port analogique du potentiomètre 2
int PotLum = A3; // Port analogique du potentiomètre 3

//Paramètres de déclenchements de la porte
int Mouv = 0; // Minute d'ouverture
int Mferm = 0; // Minute de fermeture
int vPotHouv = 0;      // Variable où on stock la valeur du potentiomètre
int vPotHferm = 0;      // Variable où on stock la valeur du potentiomètre
int vPotLum = 0;      // Variable où on stock la valeur du potentiomètre
float Houv = 8;  // Variable où on stock l'heure d'ouverture
float Hferm = 20;  // Variable où on stock l'heure de fermeture
float LumD = 20;  // Variable où on stock le seuil de lumière qui sera utilisé

//Introduction de variables
int Year;
int Month;
int Date;
int Hour;
int Minute;
int Second;
int interval = 1;
int Minute_last;
int Date_last;
int i;  //i permettra à l'arduino de savoir si il fait jour ou nuit
int PR; // Varible qui stockera la valeur de la photorésistance

void setup()
{
  Serial.begin(9600); //Initialise le moniteur série
  Wire.begin(); //Initialisation du bu I2C
  
  // Defini tous les ports du controleur moteur comme des sorties
  pinMode(enA, OUTPUT);
  pinMode(in1, OUTPUT);
  pinMode(in2, OUTPUT);
  analogWrite(enA, 255); 
  DateTime now = RTC.now();
  Minute = now.minute();
  
  // cette fonction va permettre de determiner si il fait jour ou si il fait nuit et de définir i en conséquence. 
  if (Hour >= Houv && Hour <Hferm) {
    i = 1 ; // I prend 1 ce qui veut dire qu'il fait jour
  }
  else {
    i = 0 ; // I prend 0 ce qui veut dire qu'il fait nuit
  }
}
void loop()
{  
  delay(1000);
  PR = analogRead(photoR); // On lit la valeur de la photo-resistance
  vPotHouv = analogRead(PotHouv); // on lit la valeur du potentiometre 1 
  vPotHferm = analogRead(PotHferm); // on lit la valeur du potentiometre 2
  vPotLum = analogRead(PotLum); // on lit la valeur du potentiometre 3
  Houv = ((vPotHouv*7.00/1023.00)+3); // Calcul de l'heure d'ouverture
  Hferm = ((vPotHferm*8.00/1023.00)+15); // Calcul de l'heure de fermeture
  LumD = ((vPotLum*400.00/1023.00)+623); // Calcul du seuil de luminosité 
  affichage();
  
  if (Hour >= Houv && Hour < Hferm && i == 0 && PR > LumD) { // Si l'heure est supérieur à l'heure minimale d'ouverture et que la porte est fermé
      ouverture(); // Ouverture de la porte
   }
  if (Hour >= Hferm && Hour > Houv && i == 1 && PR < LumD) { // Si l'heure est supérieur à l'heure minimale de fermeture et que la porte est fermé
      fermeture(); // Ouverture de la porte
   }
  DateTime now = RTC.now();
  Year = now.year();
  Month = now.month();
  Date = now.day();
  Hour = now.hour();
  Minute = now.minute();
  Second = now.second();
}

// Fonction permettant l'ouverture de la porte
void ouverture(){
  Serial.println();
  Serial.print("Ouverture de la porte...");
  while (digitalRead(pin_buttonA) == HIGH){ // Tant que le bouton est en position High, le moteur tourne
      //le moteur tourne
      digitalWrite(in1, HIGH);
      digitalWrite(in2, LOW);
  }
  Serial.println();
  Serial.print("Porte ouverte ;-)");
  digitalWrite(in1, LOW);
  digitalWrite(in2, LOW);
  i = 1; // I defini l'etat d'ouverture de la porte, ici i prend la valeur 1 ce qui signifie que la porte est ouverte
  delay(1000);
}

// Fonction permettant la fermeture de la porte
void fermeture(){
  Serial.println();
  Serial.print("Fermeture de la porte...");
  while (digitalRead(pin_buttonB) == HIGH){ // Tant que le bouton est en position High, le moteur tourne
      //le moteur tourne
      digitalWrite(in1, LOW);
      digitalWrite(in2, HIGH);
  }
  Serial.println();
  Serial.print("Porte ferme ;-)");
  digitalWrite(in1, LOW);
  digitalWrite(in2, LOW);
  i = 0;
  delay(1000);
}

// Fonction permettant l'affichage des données sur le moniteur serie
void affichage() {
  Serial.println();
  Serial.print("Date: ");
  Serial.print(Year);
  Serial.print("/");
  Serial.print(Month);
  Serial.print("/");
  Serial.print(Date);
  Serial.print(" ");
  Serial.print(Hour);
  Serial.print(":");
  Serial.print(Minute);
  Serial.print(":");
  Serial.print(Second);
  Serial.println();
  Serial.print("Parametres: ");
  Serial.print(Houv);
  Serial.print("  ");
  Serial.print(Hferm);
  Serial.print("  ");
  Serial.print(LumD);
  Serial.println();
  Serial.print("Valeur actuel de la Photo-resistance : ");
  Serial.println(PR);
}
```

</br></br>
## 4/ Références et développement. 
J'ai dans un premier temps étudié le fonctionnement d'un potentiomètre. J'ai utilisé [ce tutoriel](https://ledisrupteurdimensionnel.com/arduino/lecture-potentiometre-entrees-analogiques-arduino/) qui donne un schèma de montage d'un potentiomètre : </br>
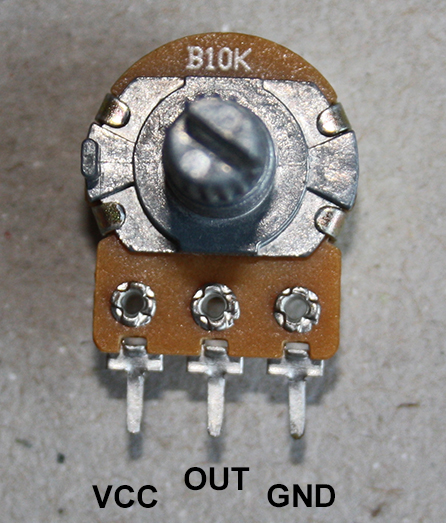
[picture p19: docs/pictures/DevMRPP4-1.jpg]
DevMRPP4-1
</br>
*Crédit : Le distributeur dimensionnel.com*

 - La broche VCC devra être branché au 5V
 - La broche Out à une broche analogique (A0...A5)
 - La broche GND à une masse de l'Arduino

J'ai utilisé son code que j'ai légèrement modifié (nommage de la broche de lecture du signal, ici A1).

```cpp
int valeur = 0;      // Variable où on stock la valeur du potentiomètre
float tension = 0;  // Variable où on stock le voltage, la tension
int PotH = A1;      // Variable qui stock la broche du potentiomètre

void setup() {
  Serial.begin(9600); // Initialisons la communication sérial
}

void loop() {
  valeur = analogRead(PotH);           // on lit la valeur du pin A0 
  tension = (valeur*5.00/1023.00);   // on calcule la tension
  Serial.print("valeur analogique: ");
  Serial.print(valeur);

  Serial.print(" tension: ");
  Serial.print(tension);
  Serial.println("V");
  delay(1000);
}
```

Ce code renvoi via le moniteur série une valeur analogique de 0 à 1023 quelque soit la valeur du potentiomètre utilisé. 
Il renvoi aussi une valeur de tension obtenu par un produit en crois détaillé dans le tutoriel. Je vais modifier ces valeurs pour calculer non pas une tension mais un horaire. Ce qui permettra au potentiomètre de régler une heure allant de 3h du matin à 10h.

```cpp
int vPot = 0;      // Variable où on stock la valeur du potentiomètre
float Houv = 8;  // Variable où on stock le voltage, la tension
int PotH = A1;      // Variable qui stock la broche du potentiomètre

void setup() {
  Serial.begin(9600); // Initialisons la communication sérial
}

void loop() {
  vPot = analogRead(PotH);           // on lit la valeur du pin A1 
  Houv = ((vPot*7.00/1023.00)+3);  
  Serial.print("valeur analogique: ");
  Serial.print(vPot);

  Serial.print(" Heure minimale d'ouverture: ");
  Serial.print(Houv);
  Serial.println("H am");
  delay(1000);
}
```

J'ai encore un peu modifier le code afin d'ajouter un second potentiomètre pour l'heure de fermeture. 
```cpp
int vPotHouv = 0;      // Variable où on stock la valeur du potentiomètre
int vPotHferm = 0;      // Variable où on stock la valeur du potentiomètre
float Houv = 8;  // Variable où on stock le voltage, la tension
float Hferm = 20;  // Variable où on stock le voltage, la tension
int PotHouv = A1;      // Variable qui stock la broche du potentiomètre
int PotHferm = A2;      // Variable qui stock la broche du potentiomètre

void setup() {
  Serial.begin(9600); // Initialisons la communication sérial
}

void loop() {
  vPotHouv = analogRead(PotHouv);           // on lit la valeur du pin A0 
  vPotHferm = analogRead(PotHferm);           // on lit la valeur du pin A0 
  Houv = ((vPotHouv*7.00/1023.00)+3); 
  Hferm = ((vPotHferm*7.00/1023.00)+16);  
  Serial.print("valeur analogique ouverture: ");
  Serial.print(vPotHouv);
  Serial.println();
  Serial.print("valeur analogique fermeture: ");
  Serial.print(vPotHferm);
  Serial.println();
  Serial.print("Heure minimale d'ouverture: ");
  Serial.print(Houv);
  Serial.println(" H");
  Serial.print("Heure minimale de fermeture: ");
  Serial.print(Hferm);
  Serial.println(" H");
  delay(2000);
}
```

Pour finir j'ajoute un troisième potentiomètre qui permettra de régler le seuil de luminosité à laquelle on souhaite que la porte se déclenche. 

```cpp
int vPotHouv = 0;      // Variable où on stock la valeur du potentiomètre
int vPotHferm = 0;      // Variable où on stock la valeur du potentiomètre
int vPotLum = 0;      // Variable où on stock la valeur du potentiomètre
float Houv = 8;  // Variable où on stock l'heure d'ouverture
float Hferm = 20;  // Variable où on stock l'heure de fermeture
float LumD = 20;  // Variable où on stock le seuil de lumière qui sera utilisé
int PotHouv = A1;      // Variable qui stock la broche du potentiomètre 1
int PotHferm = A2;      // Variable qui stock la broche du potentiomètre 2
int PotLum = A3;      // Variable qui stock la broche du potentiomètre 3

void setup() {
  Serial.begin(9600); // Initialisons la communication sérial
}

void loop() {
  vPotHouv = analogRead(PotHouv);           // on lit la valeur du pot 1 
  vPotHferm = analogRead(PotHferm);           // on lit la valeur du pot 2
  vPotLum = analogRead(PotLum);           // on lit la valeur du pot 3
  Houv = ((vPotHouv*7.00/1023.00)+3); 
  Hferm = ((vPotHferm*7.00/1023.00)+16);
  LumD = ((vPotLum*400.00/1023.00)+623);   
  Serial.print("Analog ouverture: ");
  Serial.print(vPotHouv);
  Serial.println();
  Serial.print("Analog fermeture: ");
  Serial.print(vPotHferm);
  Serial.println();
  Serial.print("Analog declenchement: ");
  Serial.print(vPotLum);
  Serial.println();
  Serial.print("Heure minimale d'ouverture: ");
  Serial.print(Houv);
  Serial.println(" H");
  Serial.print("Heure minimale de fermeture: ");
  Serial.print(Hferm);
  Serial.println(" H");
  Serial.print("Seuil de declenchement : ");
  Serial.print(LumD);
  Serial.println();
  delay(2000);
}
```

Ces codes permettent de faire varier les trois paramètres selon :
 - **Heure d'ouverture:** de 3,00h à 10,00h ;
 - **Heure de fermeture:** de 16,00h à 23,00h ;
 - **Seuil de luminosité de déclenchement:** de 623 à 1023 ;

Pour finir, j'ai ajouté une condition dans le ```void setup``` pour définir la valeur de "i" (Etat Nuit ou Jour) afin que celui-ci soit toujours bon lorsque l'on redémarre l'Arduino. 
```cpp
  if (Hour >= Houv && Hour <Hferm) {
    i = 1 ; // I prend 1 ce qui veut dire qu'il fait jour
  }
  else {
    i = 0 ; // I prend 0 ce qui veut dire qu'il fait nuit
  }
```

</br></br>
## 5/ Améliorations
 - Ajouter un écran LCD pour donner l'heure des dernières ouvertures, fermetures et valeur de lumière. 
 - Si la lecture de l'intensité lumineuse pose un problème, peut-être étudier des techniques de lissage de courbe tel qu'utiliser une moyenne glissante, [comme documenté ici](https://www.aranacorp.com/fr/implementation-de-la-moyenne-glissante-dans-arduino/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,l'%C3%A9tablissement%20de%20la%20moyenne.).

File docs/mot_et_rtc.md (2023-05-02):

# DEV -- Un moteur piloté à l'heure
## 1/ Introduction
La première étape du développement de cet outil est de chercher à piloter un moteur à courant continu de 1,5 à 3V au moyen d'une arduino UNO et d'une RTC pour donner l'heure. 
 - Dans cette configuration 1 bouton poussoir symbolise, les deux fins de courses. Le moteur devra s'arrêté lorsque ce bouton sera enclenché.
 - Une RTC permettra de fournir l'heure en temps réel. Cette donnée permet à la porte de s'ouvrir et de se fermer. 

## 2/ Matériel et fournitures nécessaire
### 2.1 Fournitures
|Dénomination|Visuel|Où se fournir ?|Qt|
|---|---|-----|--|
|Arduino UNO||Conrad / RS components|1|
|Contrôleur moteur - Module L298N|DevMR2-1|Conrad / RS components|1|
|Moteur DC (1,5-3v et son reducteur)|DevMR2-2|RS components|1|
|Module horloge RTC DS3231||Conrad / RS components|1|
|Résistances 1Kohm ou autre valeur|||3|
|Bouton poussoir|||1|
|Batterie 9V ou Bloc piles 9v et pile||Conrad / RS components|1|
|Breadbord|||1|
|Fils de breadbord mâle-mâle et femelle-mâle||||

### 2.2 Matériel
 - Ordinateur
 - [Logiciel Arduino IDE](https://www.arduino.cc/en/software)
 - Câble USB type B vers USB. 
 
## 3/ Réalisation
### 3.1 Hardware
Réaliser le circuit suivant


### 3.2 Software
Flasher au moyen d'Arduino IDE le code suivant :

```cpp
#include <Wire.h> // for SD stock
#include "DS3231.h" // for rtc

RTClib RTC;
DS3231 Clock;

// connect motor controller pins to Arduino digital pins
// motor one
int Houv = 8;
int Mouv = 56;
int Hferm = 17;
int Mferm = 57;
int enA = 4;
int in1 = 3;
int in2 = 2;
int pin_button = 7; // port numérique lié au bouton poussoir
int Year;
int Month;
int Date;
int Hour;
int Minute;
int Second;
int tempC;
int interval = 1;
int Minute_last;
int Date_last;
int i = 0;

void setup()
{
  //Initialize Serial Monitor

  Serial.begin(9600);
  Wire.begin(); //for DS3231 for RTC
  // set all the motor control pins to outputs
  pinMode(enA, OUTPUT);
  pinMode(in1, OUTPUT);
  pinMode(in2, OUTPUT);
  analogWrite(enA, 255); 
  DateTime now = RTC.now();
  Minute = now.minute();
}
 
void loop()
{  
  delay(1000);
  Serial.println();
  Serial.print(Year);
  Serial.print("/");
  Serial.print(Month);
  Serial.print("/");
  Serial.print(Date);
  Serial.print(" ");
  Serial.print(Hour);
  Serial.print(":");
  Serial.print(Minute);
  Serial.print(":");
  Serial.print(Second);
  if (Hour >= Houv && Hour < Hferm && i == 0) { // Si l'heure est supérieur à l'heure minimale d'ouverture et que la porte est fermé
      ouverture(); // Ouverture de la porte
   }
  if (Hour >= Hferm && Hour > Houv && i == 1) { // Si l'heure est supérieur à l'heure minimale de fermeture et que la porte est fermé
      fermeture(); // Ouverture de la porte
   }
  DateTime now = RTC.now();
  Year = now.year();
  Month = now.month();
  Date = now.day();
  Hour = now.hour();
  Minute = now.minute();
  Second = now.second();
  tempC = Clock.getTemperature();
}

void ouverture(){
  Serial.println();
  Serial.print("Ouverture de la porte...");
  while (digitalRead(pin_button) == HIGH){ // Tant que le bouton est en position High, le moteur tourne
      //le moteur tourne
      digitalWrite(in1, HIGH);
      digitalWrite(in2, LOW);
  }
  Serial.println();
  Serial.print("Porte ouverte ;-)");
  digitalWrite(in1, LOW);
  digitalWrite(in2, LOW);
  i = 1;
  delay(1000);
}
void fermeture(){
  Serial.println();
  Serial.print("Fermeture de la porte...");
  while (digitalRead(pin_button) == HIGH){ // Tant que le bouton est en position High, le moteur tourne
      //le moteur tourne
      digitalWrite(in1, LOW);
      digitalWrite(in2, HIGH);
  }
  Serial.println();
  Serial.print("Porte fermé ;-)");
  digitalWrite(in1, LOW);
  digitalWrite(in2, LOW);
  i = 0;
  delay(1000);
}
```

## 4/ Références et développement. 
J'ai commencé par tester des codes proposé sur le web. Mais tous me rendent des erreurs lié à des librairies.
 - [Ce Tutoriel est réalisé à partir d'un L298N](https://www.instructables.com/Chicken-Coop-Door-Arduino-Based/). Son code ne fonctionne pas du fait d'erreur sur les librairies.
 - [Ce dépot Git Hub peut être intéréssant aussi](https://github.com/chrisuthe/CoopDoor/tree/master/ChickenDoorController) mais comme le précédent il ne fonctionne pas. 

J'ai donc décidé de coder le système moi même :
 - Je suis partis du Tutoriel ci attaché pour faire tourner le moteur[Code et branchements pour faire tourner un moteur avec L298N](https://www.robotique.tech/tutoriel/commander-un-moteur-par-arduino-et-le-module-l298n/). Je suis ainsi parti de ce petit code qui permet de faire tourner le moteur dans un sens puis dans l'autre : 
 ```cpp
// connect motor controller pins to Arduino digital pins
// motor one
int enA = 4;
int in1 = 3;
int in2 = 2;
void setup()
{
  //Initialize Serial Monitor
  Serial.begin(9600);
  // set all the motor control pins to outputs
  pinMode(enA, OUTPUT);
  pinMode(in1, OUTPUT);
  pinMode(in2, OUTPUT);
  analogWrite(enA, 255); 
}
 
void loop()
{  
  //le moteur tourne
  digitalWrite(in1, HIGH);
  digitalWrite(in2, LOW);
  delay(2000);
  //stop le moteur
  digitalWrite(in1, LOW);
  digitalWrite(in2, LOW);
  delay(1000);
  //le moteur tourne dans le sens inverse
  digitalWrite(in1, LOW);
  digitalWrite(in2, HIGH);
  delay(2000);
  //stop le moteur
  digitalWrite(in1, LOW);
  digitalWrite(in2, LOW);
  delay(1000);
} 
 ```

 - J'ai ajouté un bouton poussoir pour le faire tourner jusqu'à ce qu'un bouton soit enfoncé. [J'ai pour cela suivi ce guide de branchement](https://arduino.blaisepascal.fr/le-bouton-poussoir/) et utilisé la ligne de code suivante : 
 
 ```cpp
 if (digitalRead(pin_button) == HIGH) { // si le bouton est pressé ...
      state = !state; // ... inversion de la variable d'état de la LED (allumée<->éteinte)
   }
 ```
  - Sans oublier de déclarer avant le ```void setup() ``` la variable 
  ```cpp
  int pin_button = 2; // port numérique lié au bouton poussoir
  ```
 - Puis j'ai ajouté la RTC, Pour la brancher, j'ai [consulté ce tutoriel](https://arduino-france.site/i2c-scanner/) qui m'a permis de brancher correctement l'I2C sur l'Arduino

|Capteur I2C|Uno|Nano|Mega|
|---|---|---|---|
|GND|GND|GND|GND|
|VCC|3,3v|3,3v|3,3v|
|SDA|A4|A4|20|
|SCL|A5|A5|21|

 - La gestion de l'horloge est obtenu en introduisant les librairies et variables suivantes :

```cpp
#include <Wire.h> // for SD stock
#include "DS3231.h" // for rtc

RTClib RTC;
DS3231 Clock;

int Year;
int Month;
int Date;
int Hour;
int Minute;
int Second;
int interval = 1;
int Minute_last;
int Date_last;
```

 - Puis en définissant l'heure dans le setup : 

```cpp
  DateTime now = RTC.now();
```
 - Et enfin à chaque boucle du loop, on modifie ces variables : 

```cpp
  DateTime now = RTC.now();
  Year = now.year();
  Month = now.month();
  Date = now.day();
  Hour = now.hour();
  Minute = now.minute();
  Second = now.second();
```

 - J'ai mis à l'heure mon horloge en utilisant le code ci dessous. 

```cpp
// Horloge_reglage_heure
// Appel de la bibliothèque
#include <Wire.h>
// Adresse I2C de l'horloge en temps réel
#define ADRESSE_I2C_RTC 0x68
// Indiquez ici l'heure et la date :
byte heure = 00; // 0 à 23
byte minute = 20; // 0 à 59
byte seconde = 0; // 0 à 59
byte numJourSemaine = 3; // dim = 1, sam = 7
byte numJourMois = 2; // 1 à 31
byte mois = 5; // 1 à 12
byte annee = 23; // 0 à 99
void setup(){
Wire.begin();
// Change l'heure et la date de l'horloge en temps réel
Wire.beginTransmission(ADRESSE_I2C_RTC);
Wire.write(0); // Positionner le pointeur de registre sur 00h
Wire.write(decToBcd(seconde));
Wire.write(decToBcd(minute));
Wire.write(decToBcd(heure));
Wire.write(decToBcd(numJourSemaine));
Wire.write(decToBcd(numJourMois));
Wire.write(decToBcd(mois));
Wire.write(decToBcd(annee));
Wire.endTransmission();
}
void loop(){
}
// Convertir les nombres décimaux normaux en décimaux codés binaires
byte decToBcd(byte val){return( (val/10*16) + (val%10));}
```
 - Si ce dernier ne fonctionne pas, c'est probablement que l'adresse I2C n'est pas la bonne. Utiliser un code de détection de port pour y parvenir. Ouvrir le moniteur série. L'adresse retourné par ce programme permettra de remplacer ```0x68``` dans le programme précédent à la ligne ```#define ADRESSE_I2C_RTC 0x68```

```cpp
/*=================================================================
Ce sketch est un scanner I2C: il essaye de communiquer avec toutes 
les adresses I2C possibles et affiche celle(s) qui réponde(nt).
  
                      BRANCHEMENT
* Pin SCD du moule à scanner  ----------->  SCD de l’Arduino
* Pin SDA du moule à scanner  ----------->  SDA de l’Arduino
================================================================ */

#include <Wire.h>
void setup()
{
  Wire.begin();
  Serial.begin(9600);
  Serial.println("\nI2C Scanner");
}

void loop()
{
  byte error, address;
  int nDevices;
  Serial.println("Recherche en cours...");
  nDevices = 0;
  for(address = 1; address < 127; address++ ) 
  {
    Wire.beginTransmission(address);
    error = Wire.endTransmission();

    if (error == 0)
    {
      Serial.print("Equiment I2C trouve a l'addresse 0x");
      if (address<16) 
        Serial.print("0");
      Serial.print(address,HEX);
      Serial.println("  !");
      nDevices++;
    }
    else if (error==4)
    {
      Serial.print("Erreur inconnue a l'address 0x");
      if (address<16) 
        Serial.print("0");
      Serial.println(address,HEX);
    }    
  }
  if (nDevices == 0)
    Serial.println("Aucun Equipement I2C trouve\n");
  else
    Serial.println("Fini\n");

  delay(5000);           
}
```

## 5/ Améliorations
 - Ajouter un second bouton poussoir. (Un poussoir pour la descente et un autre pour la montée).
 - Ajouter carte SD pour stocker les données de commandes d'horaire. Ce qui veut dire que les variables devront être lu dans un fichier qui se trouvera dans la SD carte.

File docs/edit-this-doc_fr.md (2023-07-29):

# Éditer cette documentation

## 1/ Introduction
|||
|-|-|
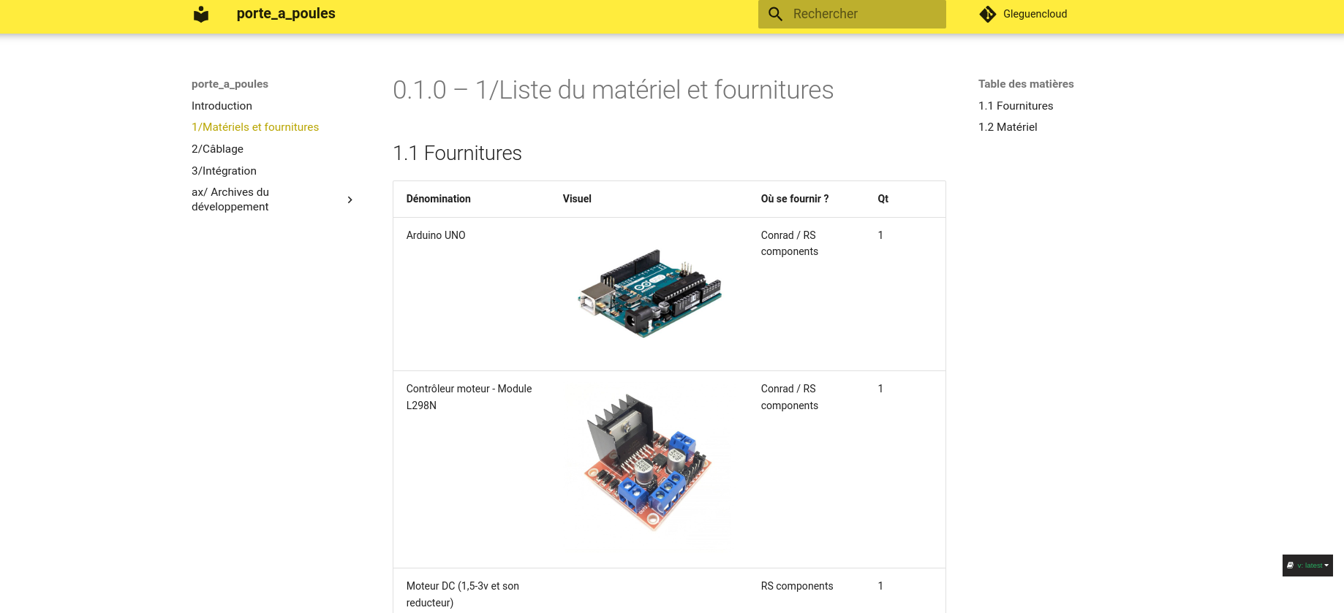
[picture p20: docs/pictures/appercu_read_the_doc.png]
ED1-1
|Cette documentation est mise en page par ReadTheDocs.org et [lisible à l'adresse ci attaché](https://porte-a-poules.readthedocs.io/fr/latest/). En aucun cas, cette adresse permet d'éditer la documentation.||
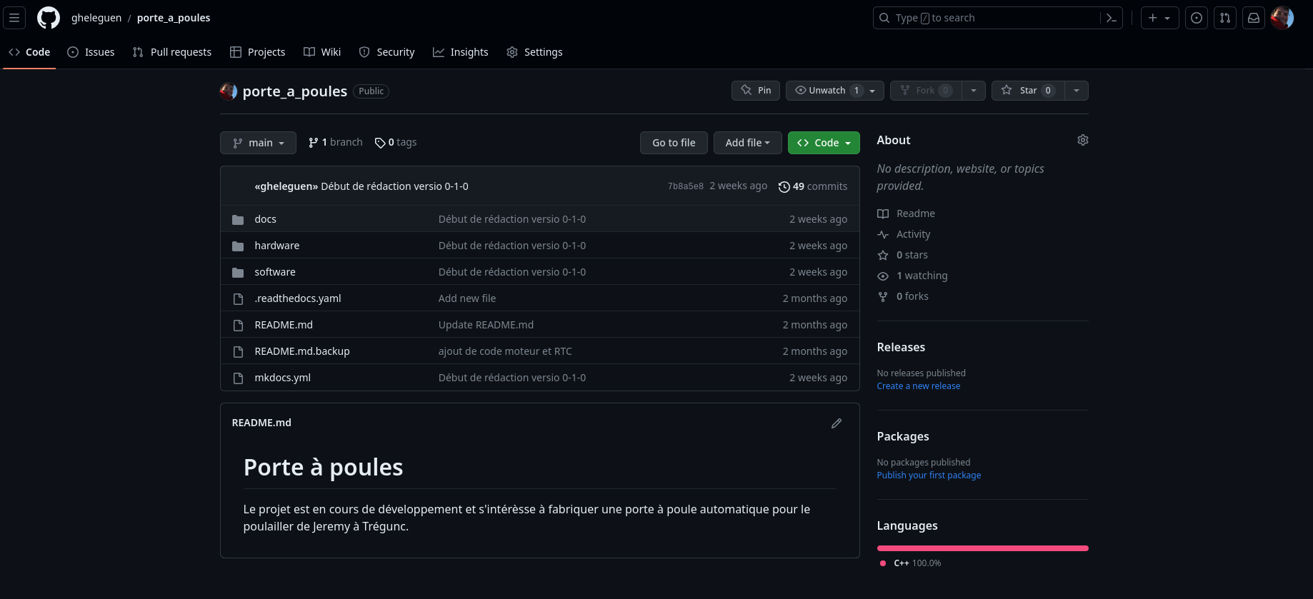
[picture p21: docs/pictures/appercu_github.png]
ED1-2
|Afin de pouvoir contribuer à cette documentation, vous pouvez contribuer directement au [repository GitHub](https://github.com/gheleguen/porte_a_poules).||

C'est sur GitHub que sont déposés les fichiers sources. On y retrouve l'arborescence suivante : 

 - **docs :** Est le dossier qui contient les documents qui pourront être affichés sur le read the doc. Dans ce dossier sont entreposés :

   - A la racine les fichiers marckdown qui sont les textes de la documentation. Pour chaque onglet sur read the doc nous ajouterons un fichier séparé avec un titre en Anglais sans espaces terminé par "_fr" pour la version française ou "_en" pour le version anglaise. L'extention sera toujours ".md".
   - Le dossier "pictures" : Qui contient plusieurs dossiers dont chacun porte un nom en rapport avec le fichier marckdown auquel il se rapporte. Ainsi pour un fichier de doccumentation "test1_fr.md" on prendra le soin d'entreposer les images dans un dossier "/docs/pictures/test1".

 - **Hardware :** Qui est le dossier qui contient les fichiers d'impressions 3D, de découpe laser...  

Avant de faire une proposition de contribution, il est bienvenue d'éditer le repository depuis votre compte en effectuant un forke de la présente documentation. Une fois que vous aurez une version prête à être publiée il suffira de faire une pull request au "main project".
C'est un administrateur qui étudiera votre proposition pour en intégrer tout ou partie sur le projet. 

## 2/ Édition (généralités)
Ces actions peuvent se réaliser directement sur la plateforme gilhub.

### 2.1 Écriture en Marckdown
Le Marckdown est un langage de mise en forme de texte très simplifié. On peut éditer un fichier ".md" directement via gitHub ou en local de son ordinateur avec n'importe quel éditeur de texte. Cependant nous recommandons [Ghostwriter](https://ghostwriter.kde.org/fr/) qui présente l'avantage de proposer une vue en direct du rendu (aperçu HTML).

[Pour ce qui est de la syntaxe, consulter ce guide](https://www.markdownguide.org/basic-syntax/)

### 2.2 Ajout et mise à jour d'une image

#### 2.2.1 Ajout
Les images que l'on souhaite faire apparaître dans la documentation ne doivent pas être collées dans le document. 

 - Importer les images désirées que l'on aura préalablement réduites en taille chacune en dessous de 200Ko et renommées de manière à être facilement identifiables. 
 - Dans le fichier de documentation corespondant à la ligne où l'on souhaite faire apparaître l'image, ajouter la ligne suivante : 
 ```Legende_Image``` 

#### 2.2.2 Mise à jour 
Pour mettre à jour une image, il suffit de supprimer du git l'image en question et d'uploader la nouvelle image en prenant soin de renommer cette nouvelle image avec le nom exact de l'ancienne. 

## 3/ Édition du dépôt en locale (Intermédiaire)
Cette méthode permet de cloner l'archive disponible sur github sur un disque dure. Ainsi on pourra facilement modifier les différents fichiers mais aussi l'arborescence sans nécéssiter de connexion internet mais surtout cela va permettre de préparer une version qui pourra par la suite faire l'objet d'un pull request. 
Toute la démarche décrite ci-dessous est valable uniquement pour un usage depuis un ordinateur sous Linux. Il existe nécessairement des équivalent pour les autres OS mais les lignes de commandes restent les même.

### 2.1 Installer Git et préparer le terrain
 - Sur votre disque dure, définir l'espace où sera stocké le dépôt. Sachez qu'un dépôt GitHub peut peser jusq'à 500Mo. De préférence définir un dossier vide. **Attention* A ce qu'aucun dossier ou sous-dossier du chemin ne comporte de caractères spéciaux ou d'espaces. Remplacer tous les espaces par des underscore "_". 
 - Ouvrir un terminal (*Ctrl + Alt + t* sur Unbuntu).
 - Dans le cas où le paquet "git" n'est pas déjà installé sur votre PC, lancez l'installation de git :  ```sudo apt install git``` (Cette action nécessite une connexion internet).

### 2.2 Cloner le dépôt sur son disque dure
 - Ouvrir une page web avec le github que l'on souhaite cloner
 - Y copier le code "https" que l'on trouvera dans l'onglet déroulant "code" en haut à droite.
 - Dans un terminal se diriger vers l'espace prévu pour coller le dépôt. Utiliser la commande ```cd puis_chemin/de_votre_dossier```
 - Cloner le dépôt git en utilisant la commande ```git clone https://github.com/identifiant/nom_du_projet.git``` Prendre soin de remplacer l'url par celui du dépôt désiré si il est différent du notre. 
 - Le clonage va prendre quelques minutes et va coller tous les fichiers et l'arborescence dans votre répertoire.

### 2.3 Modifier le dépôt
 - Sur votre poste de travail, modifiez tous les fichiers nécessaires, déposer des fichiers, suprimez en...
 - Avant de commencer à travailler peut-être que le dépôt en ligne a été modifié depuis votre dernière mise à jour. Pour mettre à jour votre dépôt en local. Se positionner tout d'abord dans le dépôt ```cd NomduDepot``` Puis effectuer un "Pull" ```git pull```
 
### 2.4 Proposer des modifications
Si vous avez effectué des modifications, il peut-être utile de les proposer en modification au projet. Mais avant cela il peut-être utile de créer une nouvelle branche ou de faire cela depuis votre fork. 
 - Pour ajouter l'ensemble des fichiers à la liste des fichiers à commiter : ```git add *```
 - Commiter ```git commit -m "commentaire associé au commit" git@git.cru.fr:nom_projet.git nom_branche (par défaut master représentant la branche principale)```
 - Enfin pousser votre travail ```git push```

## Liens connexes
 - [Documentation Git](https://git-scm.com/about)
 - [Formation vidéo à Git](https://youtube.com/playlist?list=PLjwdMgw5TTLXuY5i7RW0QqGdW0NZntqiP)

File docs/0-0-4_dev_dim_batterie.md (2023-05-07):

# 0.0.4 -- Elec -- Dimensionnement de la batterie

## 1/ Introduction
Cette version de la porte à poules sera installé sur

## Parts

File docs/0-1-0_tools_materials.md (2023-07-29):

# 1/Liste du matériel et fournitures
**Version 0.1.0**
<br><br>
## 1.1 Fournitures
|Dénomination|Visuel|Où se fournir ?|Qt|
|---|---|-----|--|
|Arduino UNO||Conrad / RS components|1|
|Contrôleur moteur - Module L298N|DevMR2-1|Conrad / RS components|1|
|Moteur DC (1,5-3v et son reducteur)|DevMR2-2|RS components|1|
|Module horloge RTC DS3231||Conrad / RS components|1|
|Module porte carte SD et SDHC *notes : ce modèle contient un convertisseur de tension permettant de l'alimenter en 5V comme en 3,3v*||Conrad / RS components|1|
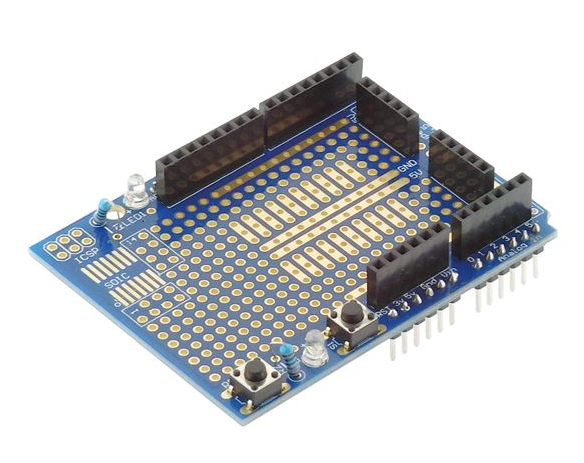
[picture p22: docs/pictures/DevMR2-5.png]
|Adafruit proto shield||Go tronic|1|
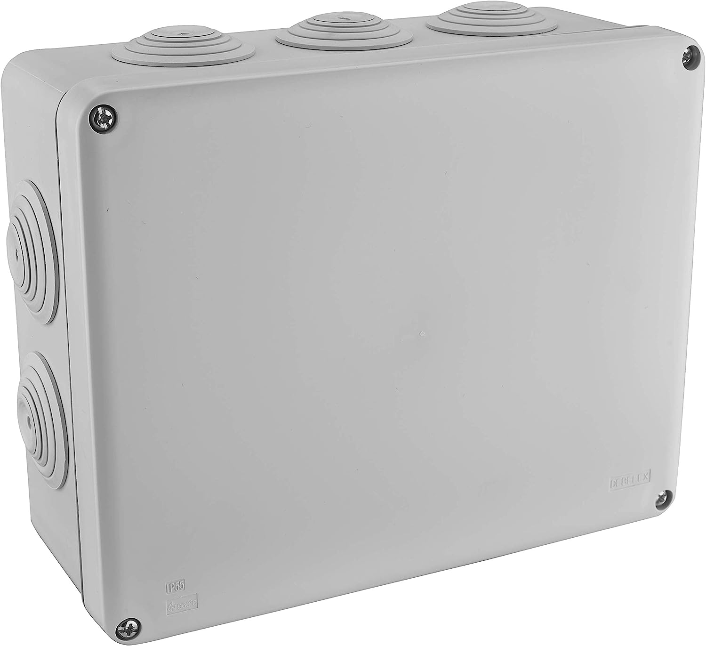
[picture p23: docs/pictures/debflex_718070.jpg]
|Boite de dérivation ||ici : DEBFLEX IP55 718070 210*170*80mm acheté chez Leroy-merlin|1|
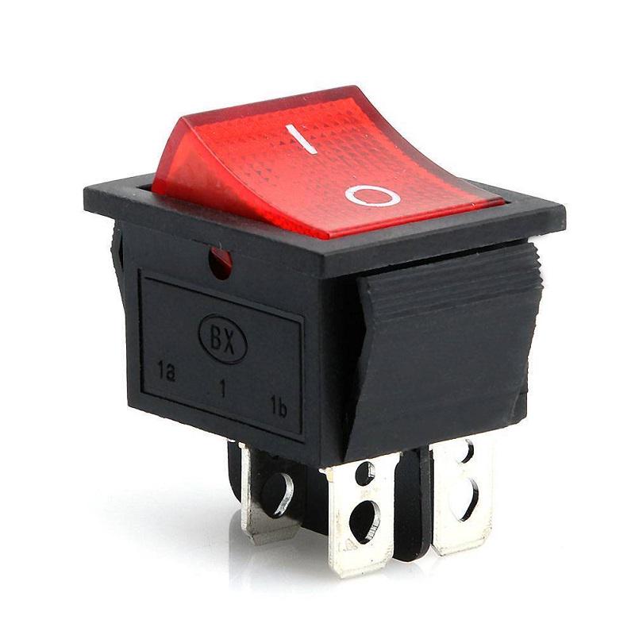
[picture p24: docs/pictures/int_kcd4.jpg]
|Interupteur étanche KCD4||Conrad / RS components|1|
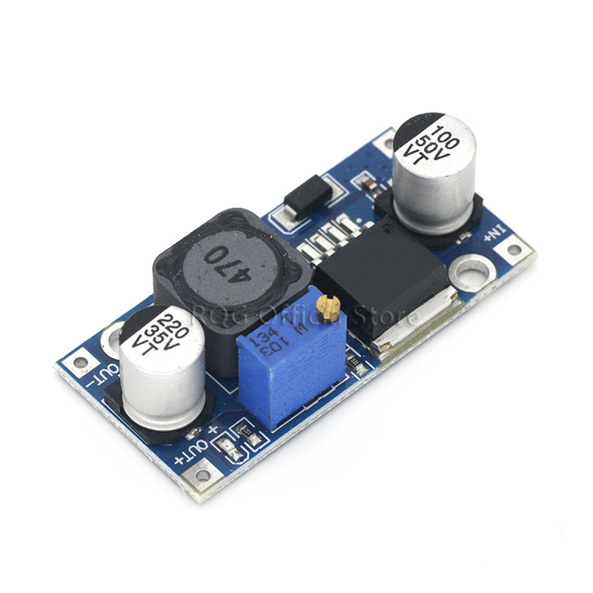
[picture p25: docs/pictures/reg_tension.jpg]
|Module abaisseur de tension LM2596S DC-DC||Conrad / RS components|1|
|Carte Micro SD||Conrad / RS components|1|
|Résistances 1Kohm ou autre valeur|||4|
|Résistances 10Kohm|||1|
|Fins de courses|||2|
|Photo-résistance|||1|
|Batterie 6V 5Ah au plomb||Conrad / RS components|1|
|Potentiomètres||Conrad / RS components|3|
|Fils de breadbord mâle-mâle et femelle-mâle||||
|Kit de connecteurs dupont|||1|
|Gaine thermo-retractable||magasin de bricolage|1|
|Jeu de cosses electriques||magasin de bricolage|1|
|Fils et câbles électrique||magasin de bricolage|1|

## 1.2 Matériel
 - Ordinateur
 - [Logiciel Arduino IDE](https://www.arduino.cc/en/software)
 - Câble USB type B vers USB
 - Pince à connecteurs dupont
 - Pince coupante
 - Pince à dénuder
 - Fer à souder
 - Etain pour soudure électronique
 - Multimètre
 - Imprimante 3D

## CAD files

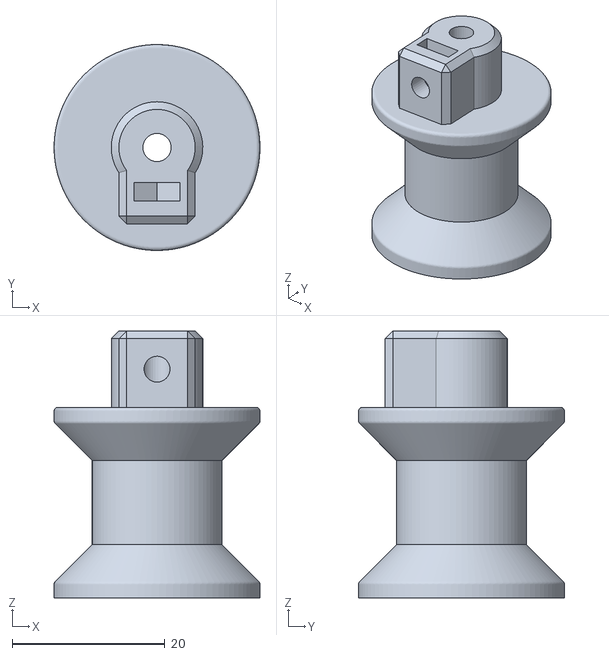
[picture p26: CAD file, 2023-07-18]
hardware/3Dprints/enrouleur_porte_poule_v0-0-5 v2.stl
27.0 x 27.0 x 35.0

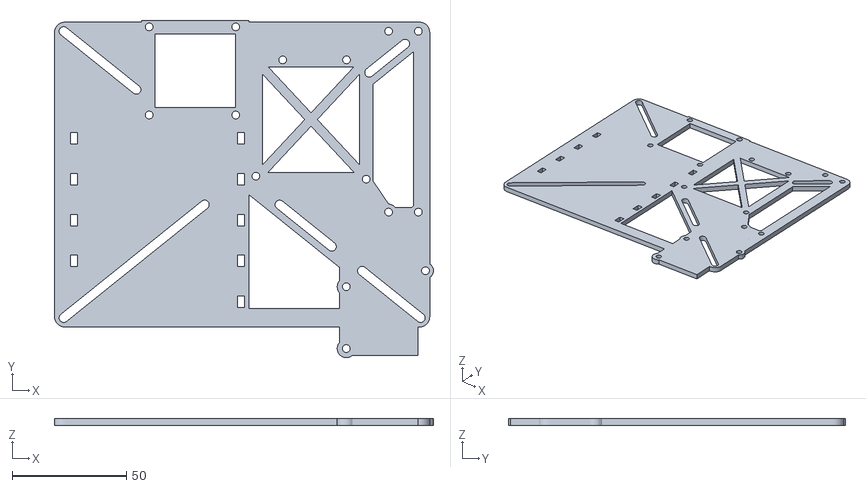
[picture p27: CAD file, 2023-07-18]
hardware/3Dprints/Plaque_primaire.stl
165.6 x 147.4 x 3.00

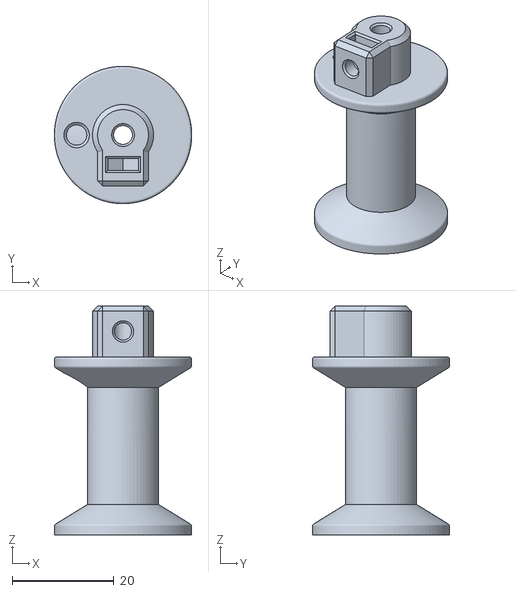
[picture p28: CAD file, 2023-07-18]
hardware/3Dprints/enrouleur_porte_poule_v0-0-5 v4.stl
27.0 x 27.0 x 45.0

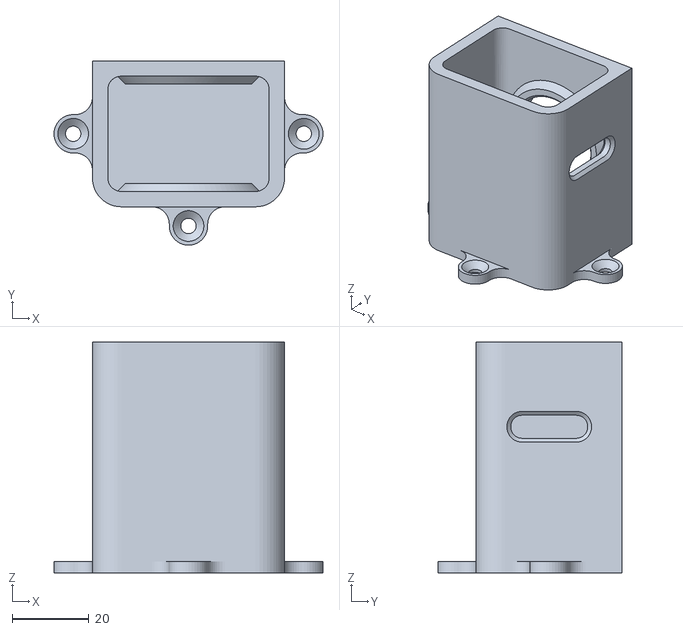
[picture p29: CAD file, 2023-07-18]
hardware/3Dprints/boite_enrouleur.stl
70.0 x 48.0 x 60.0

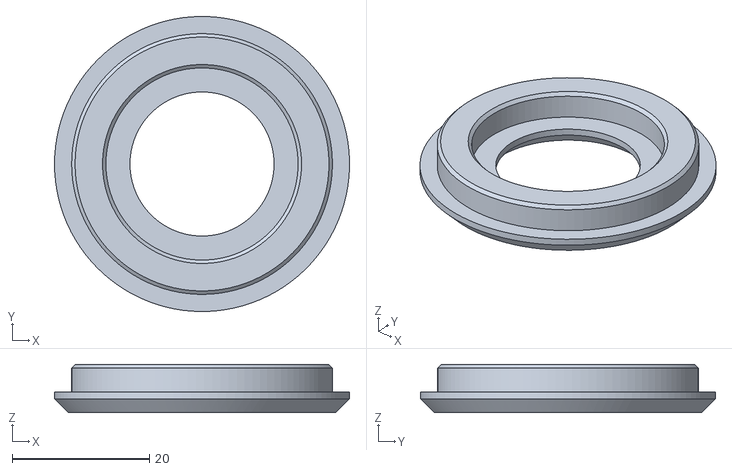
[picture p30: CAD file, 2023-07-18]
hardware/3Dprints/Anneau_oeilleton.stl
43.0 x 43.0 x 7.00

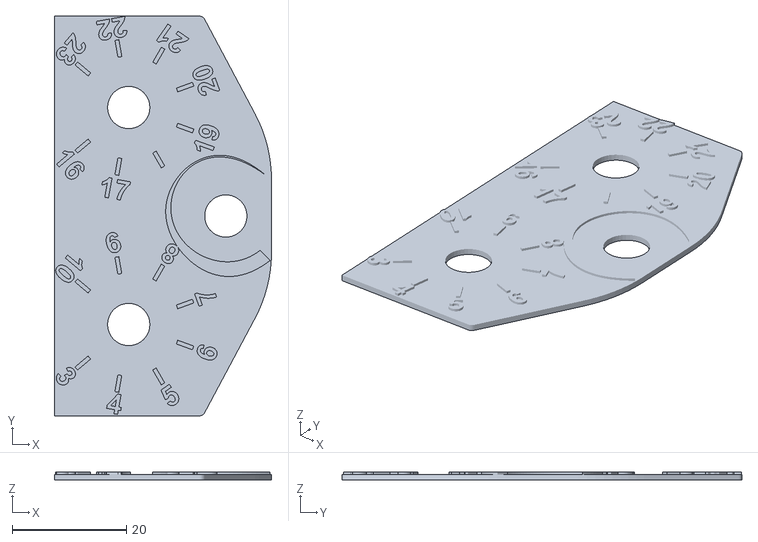
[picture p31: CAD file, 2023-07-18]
hardware/3Dprints/cadran_pot.stl
38.0 x 70.0 x 1.40

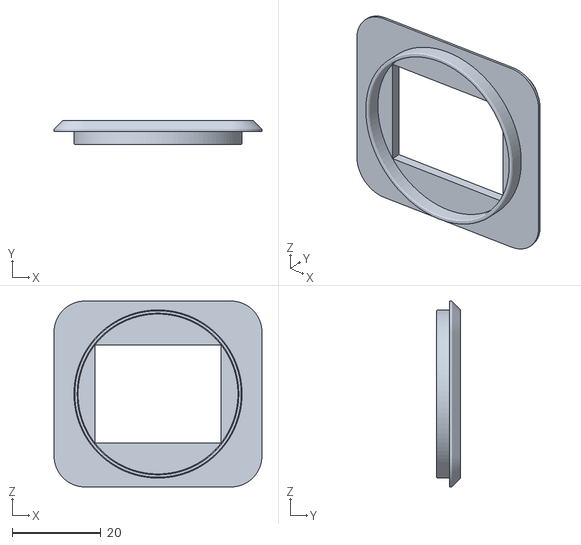
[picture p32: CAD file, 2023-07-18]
hardware/3Dprints/support_interupteur.stl
47.0 x 5.50 x 42.0

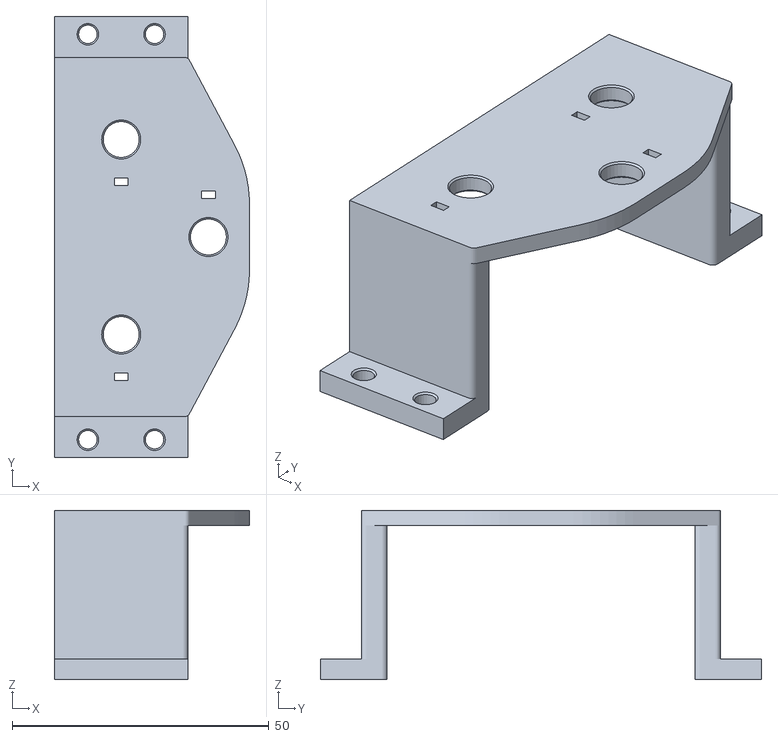
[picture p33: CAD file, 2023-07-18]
hardware/3Dprints/Porte_potentiometres_V1.stl
38.0 x 86.0 x 33.0

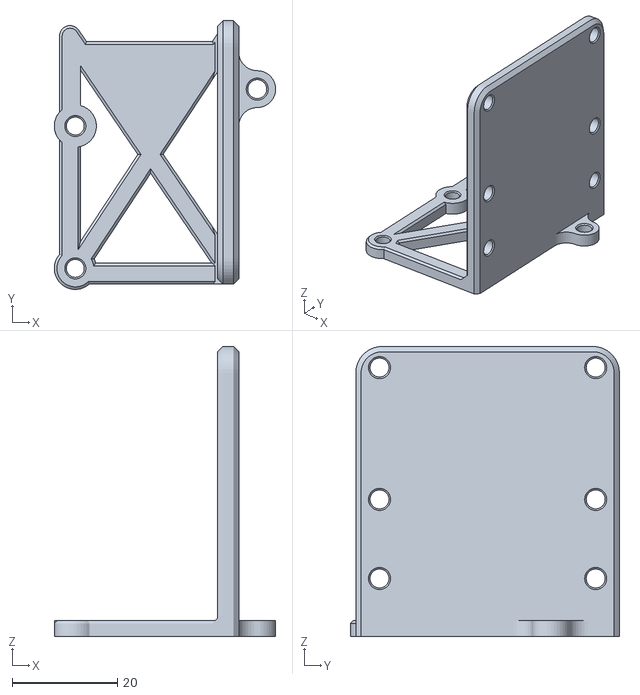
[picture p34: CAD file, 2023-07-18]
hardware/3Dprints/Support_moteur_V1.stl
42.0 x 51.0 x 55.0

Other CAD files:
hardware/3Dprints/enrouleur_porte_poule_v0-0-5 v1.stl
hardware/3Dprints/enrouleur_porte_poule_v0-0-5 v2.f3d
hardware/3Dprints/enrouleur_porte_poule_v0-0-5.f3d

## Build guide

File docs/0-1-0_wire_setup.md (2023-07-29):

# 2/Montage électronique
**Version 0.1.0**
<br><br>
## 2.1 Introduction
La version 0.1.0 est la première version à être installé sur un poulailler. Le test a été effectué en été 2023 en Bretagne à Trégunc. 

### 2.1.1 Principe de fonctionnement
Le boitier ici présent permet d'enrouler et de dérouler une corde autour d'un tambour. Ce qui dans notre cas par un jeu de poulie, permet de lever et descendre la porte d'us poulailler. 

L'utilisateur en agissant sur les trois potentiomètres peut modifier chacun de ces trois paramètres sans intervenir sur le programme : 
 - L'heure minimum d'ouverture, 
 - L'heure minimum de fermeture,
 - Le seuil de luminosité pour le déclenchement, 

Une horloge RTC, permet de conserver l'heure et la date même hors tentions. De cette manière le système connaît l'heure réel et la date. 
Une module (lecture écriture) de carte SD permet d'écrire sur un fichier .txt des données tel que les paramètres donnés par l'utilisateur, et les heures de déclenchements de la porte. Ce fichier a pour unique vocation de simplifier le débogage.

Une photo-résistance permet de mesurer la quantité de lumière ambiante. C'est cette donnée qui sert à définir le moment où s'ouvrira ou se fermera la porte.  

Les deux boutons poussoirs ou plutôt les deux fins de courses permettent au système d'avoir l'information de la position de la porte et ainsi arrêter le moteur lorsque la porte est abaissé ou ouverte. 

Dans cette version, on utilise une batterie 6v au plomb. Elle est chargé via un panneau solaire 12v et un abaisseur de tension. Le circuit d'alimentation est détaillé dans une autre partie de ce tutoriel.

Un interrupteur disposé sur le coté permettra d'ouvrir ou fermer l'alimentation du système. 
 
### 2.1.2 Recommandations
Le circuit détaillé ci-dessous est à réaliser en veillant à garder des longueurs de câbles suffisantes. Il est également recommandé d'utiliser un kit de connecteurs duponts pour faciliter les branchements. 

Par ailleur bien consulter les autres partie du tutoriel et particulièrement la partie traitant de l'intégration. En effet la longueur des câbles nécessaires dépendra de la disposition des différents éléments dans le boitier étanche. 

</br></br> 
## 2.2 Réalisation
### 2.2.1 Câblage
Réaliser le circuit représenté ci dessous. Le fichier fritzing est disponible dans le dossier "hardware" du dépôt.

Souder sur la carte "adafruit proto shield" des résistances de tirage (symbolisés par des petits fils blanc sur le shèma reliant le 5v aux boutons poussoirs et la photo-résistance).

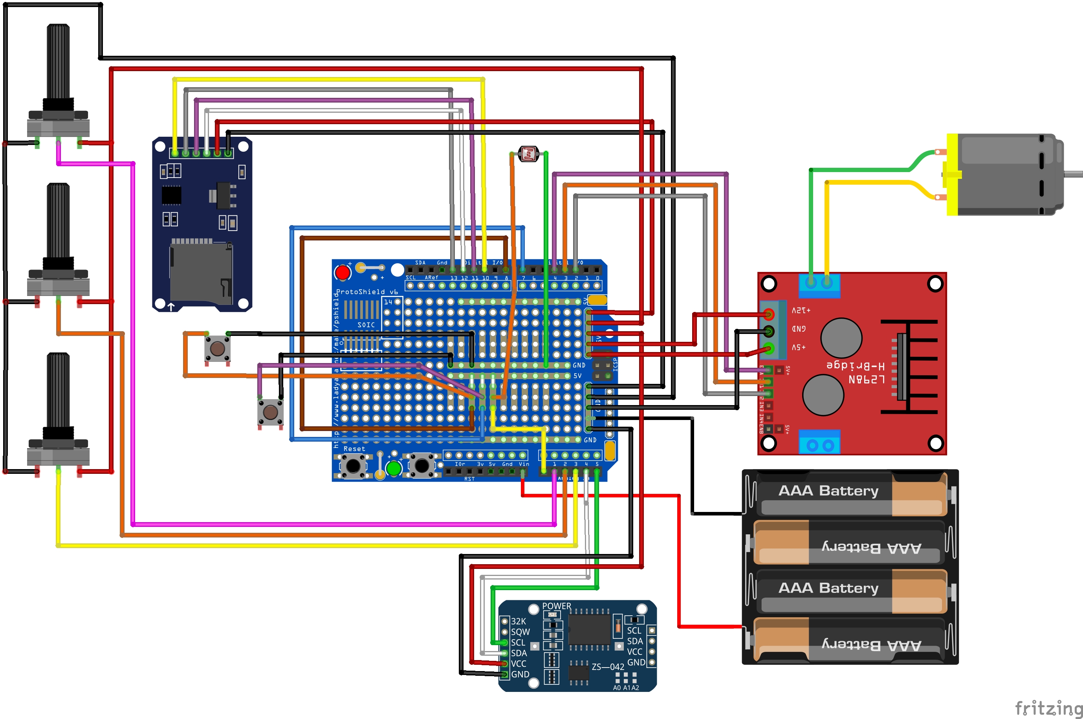
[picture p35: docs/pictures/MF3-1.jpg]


#### 3.1.2
 - Visser le réducteur du moteur sur le support au moyen de 3 vis M3 et de 3 écrous.
 - Insérer les 3 potentiomètres dans les supports en forçant. On prendra soin de placer le potentiomètre qui sert au réglage du seuil de luminosité sur la pointe. 
 - Visser le support de potentiomètres sur la droite, la carte arduino au centre et le contrôleur moteur à gauche. 
 - Visser le support de moteur en dessous du porte potentiomètres. 

</br></br>
## 2.3 Améliorations envisageables
 - Ajouter un écran LCD pour donner l'heure des dernières ouvertures, fermetures et valeur de lumière. 
 - Si la lecture de l'intensité lumineuse pose un problème, peut-être étudier des techniques de lissage de courbe tel qu'utiliser une moyenne glissante, [comme documenté ici](https://www.aranacorp.com/fr/implementation-de-la-moyenne-glissante-dans-arduino/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,l'%C3%A9tablissement%20de%20la%20moyenne.).

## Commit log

2023-05-02 ajout de code moteur et RTC
2023-05-02 ecriture dev moteur et rtc
    [Dev_Mot_et_RTC.fzz]
2023-05-02 Modif de nom pour referencer le code dev
2023-05-02 Ecriture ajout resistance photosensible
    [Dev_Mot_et_RTC.fzz, Dev_mot_rtc_photoR.fzz]
2023-05-02 Ajout d'une piste de réflexion
2023-05-03 dev 0.0.3 : Ajout de 3 potentiomètres pour régler les paramètres
    [Dev_mot_rtc_photoR_pot.fzz]
2023-05-04 Ajout d'un lecteur de carte SD pour l'écriture d'un fichier de log
    [Dev_mot_rtc_photoR_pot_SDcard.fzz]
2023-05-04 dev 0.0.4 : Modification de l'intro
2023-05-04 modif des titres des 4 versions de dev
2023-05-04 correction batterie 9V ver 5 à 6 v
    [Dev_Mot_et_RTC.fzz, Dev_mot_rtc_photoR.fzz, Dev_mot_rtc_photoR_pot.fzz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]
2023-05-05 test custom_dir: material/.overrides
2023-05-05 Revert "correction batterie 9V ver 5 à 6 v"
    This reverts commit da0694241a086180419a12e9eeec86cdcdc821a4
    [Dev_Mot_et_RTC.fzz, Dev_mot_rtc_photoR.fzz, Dev_mot_rtc_photoR_pot.fzz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]
2023-07-18 Début de rédaction versio 0-1-0
    [0-1-0_Montage_elec.fzz, Anneau_oeilleton.stl, Dev_mot_rtc_photoR_pot_SDcard.fzz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]
2023-07-29 guide de fabrication
